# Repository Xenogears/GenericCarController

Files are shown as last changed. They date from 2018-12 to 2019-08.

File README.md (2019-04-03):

# Generic Car Controller
It is a device designed to improve the capabilities of vehicles in an automotive environment.
This custom controller connects to an existing CAN Bus on the vehicle and acts like another component of the system.

### Motivation
It is very common that certain car features are locked by the manufacturers in its mid/low-series products or that its embedded systems are restricted to work with a limited array of devices.
There even are internal parameters hidden to customer's usage. These parameters may be helpful in order to predict potential malfunctions and enhances the security and the reliability of the vehicle.

### Compatibility with specific car models
Even though the project is developed and tested using an Opel Astra H (2004) it can be adapted and used with any vehicle which uses a CAN BUS network to communicate across its devices.

Other car models must be defined inside the "cars/" folder following the defined structure in the "DefaultCar" model.

### Hardware setup
The project is not closed to a specific hardware device but it is developed focusing on the ATMega brand microprocessors with multiple peripheral connected via the SPI interface.

The latest prototype version (4.3) was built using the following components:
* 1x - Arduino Nano v3 (ATMega 328p)
* 1x - MCP 2515 CAN Controller board
* 1x - MCP4131 Potentiometer
* 1x - PC817 Optocoupler
* 1x - HC-05 Bluetooth interface (Optional, used for wireless debugging and configuration)
* 1x - SIM800L GSM Module
* 1x - GY-NEO6MV2 GPS Module

You can build your own with the schematic and the gerber file located inside the "Board/" folder.
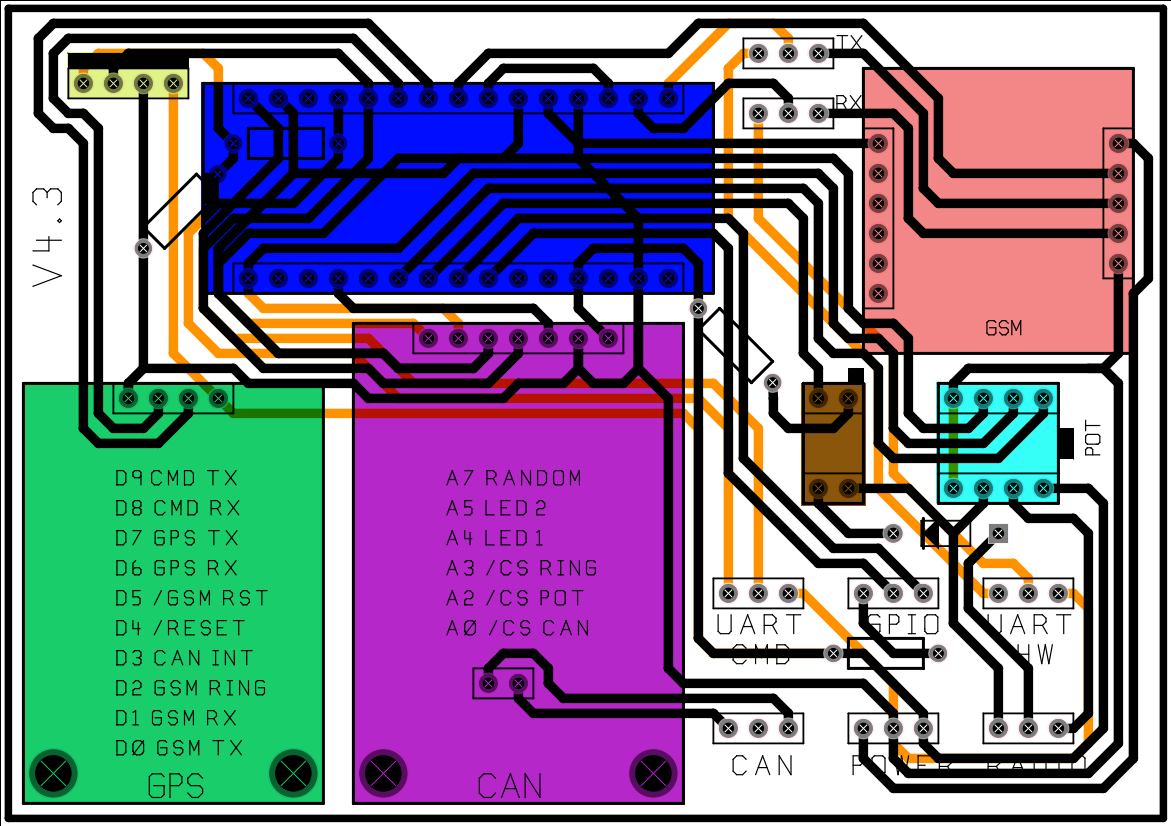
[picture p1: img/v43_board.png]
Prototype V4.3


### Previous prototypes
For learning purposes you can see inside the "img/" folder the progression of already built prototypes and how they were improved. 
<br/>
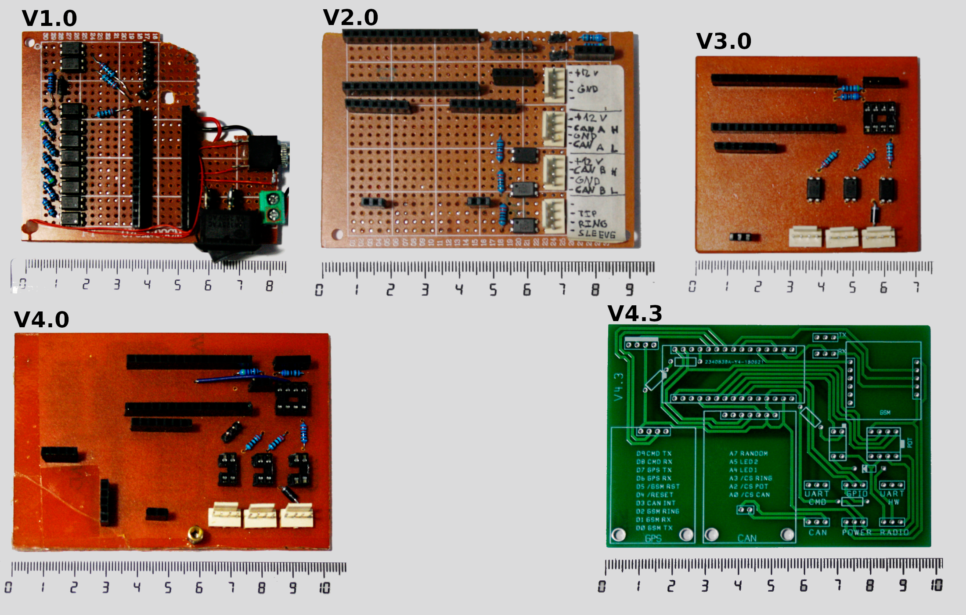
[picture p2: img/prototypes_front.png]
Prototypes (Front view)

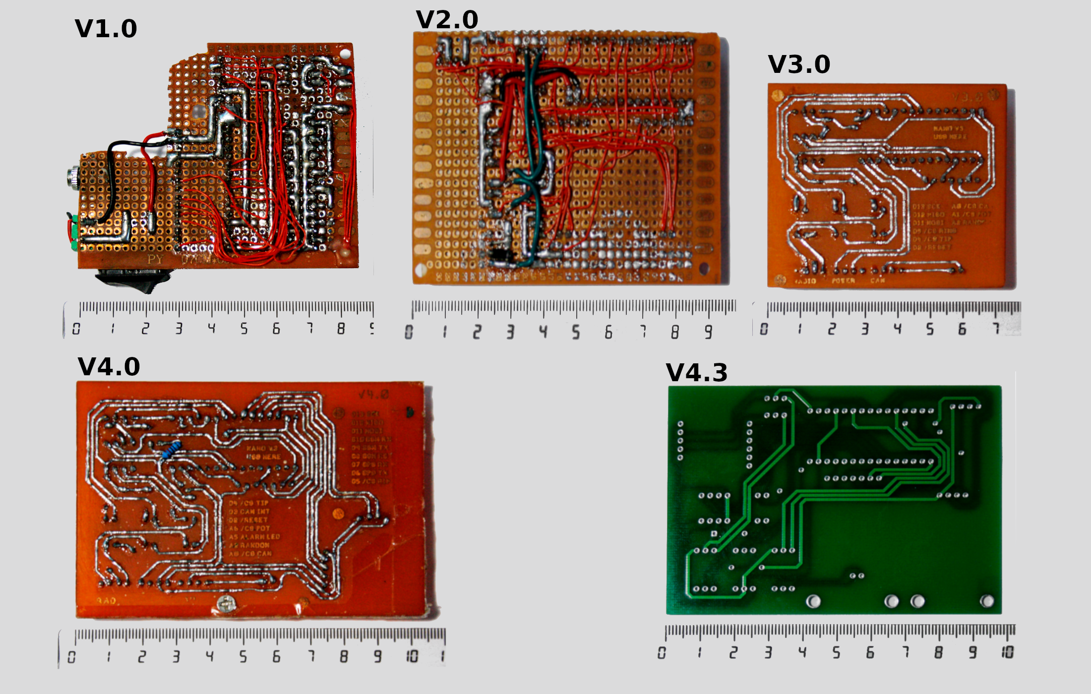
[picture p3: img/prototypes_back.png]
Prototype (Back view)


### License
Author:	  Álvaro Graciá Gil<br/>
License:	This work is licensed under a Creative Commons Attribution-NonCommercial-ShareAlike 4.0 International License<br/>
	 		    (http://creativecommons.org/licenses/by-nc-sa/4.0/)<br/>

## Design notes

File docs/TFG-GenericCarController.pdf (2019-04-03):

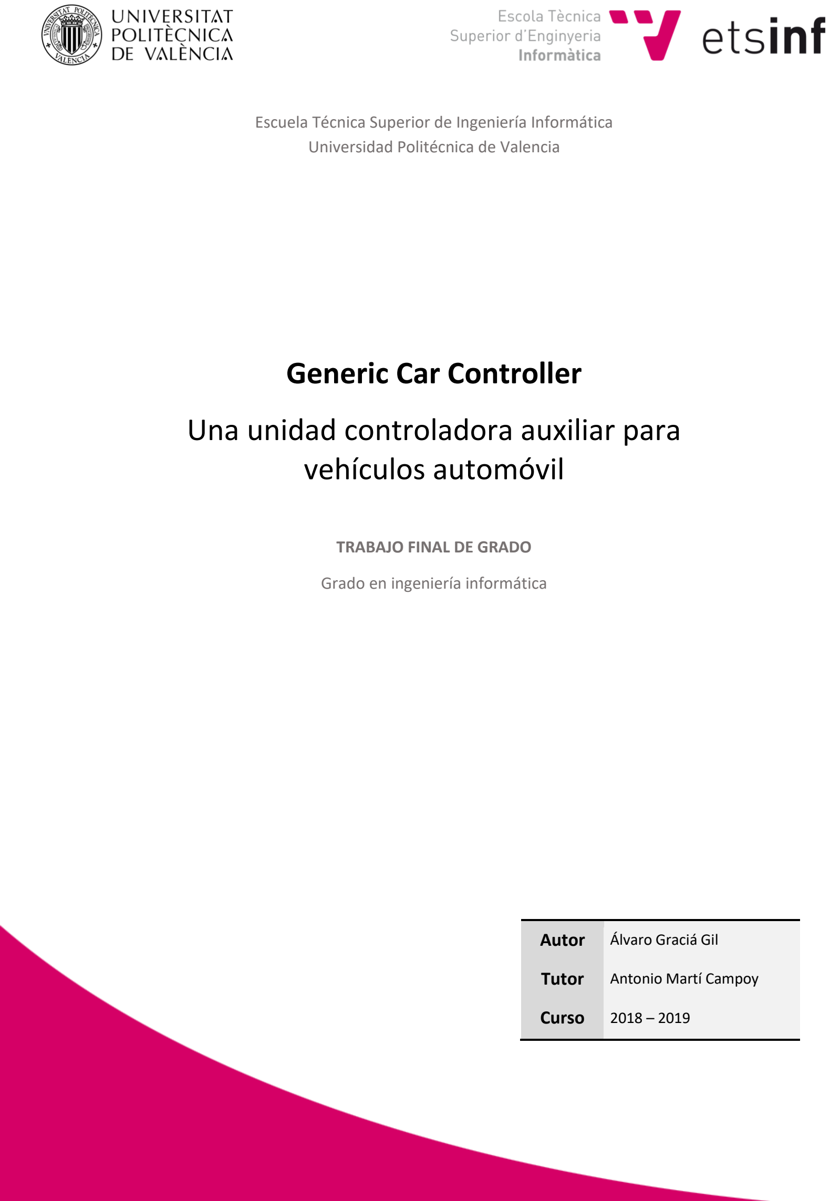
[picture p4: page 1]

Escuela Técnica Superior de Ingeniería Informática Universidad Politécnica de Valencia

# Generic Car Controller

# Una unidad controladora auxiliar para vehículos automóvil

TRABAJO FINAL DE GRADO

Grado en ingeniería informática

Autor | Álvaro Graciá Gil
Tutor | Antonio Martí Campoy
Curso | 2018 – 2019

## Esta obra está bajo una licencia de Creative Commons Reconocimiento – No Comercial – Compartir Igual 4.0 Internacional. (http://creativecommons.org/licenses/by-nc-sa/4.0/)

GitHub del proyecto https://github.com/Xenogears/GenericCarController

Dedicado a mi familia. Gracias a todos por darme la posibilidad de completar mis estudios y ayudarme durante todos estos años de formación y crecimiento personal.

## RESUMEN

Este documento trata sobre el diseño y la implementación de una controladora para vehículos automóvil.

Está formada por un componente hardware basado en un sistema microcontrolador, el cual se integra a través del bus de datos CAN en los sistemas existentes en la mayoría de los vehículos actuales. Y, por otra parte, del software específico incluido en el propio microcontrolador, el cual gestiona las comunicaciones con el automóvil y le dota de características adicionales y personalizadas.

Algunos ejemplos de las funcionalidades implementadas son:
- El control de una radio no original a través de los botones incorporados en el volante
- Un sistema de diagnóstico que permite en tiempo real la obtención de múltiples parámetros del automóvil que normalmente son inaccesibles.
- Un sistema de geolocalización 24/7.
- El uso de la pantalla original del vehículo para mostrar notificaciones y textos personalizados.
- Control y configuración del sistema a través de una aplicación móvil para Android.

Palabras clave: Controladora para vehículos automóvil, CAN BUS, Geolocalización, Arduino, Android, GPS, GSM, Traccar, Potenciómetro digital, Sistemas Empotrados

## RESUM

Aquest document tracta sobre el disseny i la implementació d’una controladora per a vehicles automòbil.

Està formada per un component hardware basat en un sistema microcontrolador, el qual s’integra a través el bus de dades CAN en els sistemes existents en la majoria dels vehicles actuals. I, d’altra banda, del software específic inclòs en el propi microcontrolador, el qual gestiona les comunicacions amb l’automòbil i el dota de característiques addicionals i personalitzades.

Alguns exemples de les funcionalitats implementades són:
- El control d’una ràdio no original a través dels botons incorporats al volant.
- Un sistema de diagnòstic que permet en temps real l’obtenció de múltiples paràmetres de l’automòbil que normalment són inaccessibles.
- Un sistema de geolocalització 24/7.
- L’us de la pantalla original del vehicle per mostrar notificacions i textos personalitzats.
- Control i configuració del sistema mitjançant una aplicació mòbil per a Android.
Paraules clau: | Controladora per a vehicles automòbil, CAN BUS, | Geolocalització, Arduino,
Android, GPS, GSM, Traccar, Potenciòmetre digital, Sistemes Encastats.

## ABSTRACT

This document deals with the design and the implementation of a custom controller for an automotive vehicle.

It consists of a hardware component based on a microcontroller system, which uses a CAN data bus to integrate with the existing systems available in the majority of current vehicles. And, on the other hand, the specific software included in the microcontroller itself, which manages the communications with the vehicle and gives it additional and personalized functions.

Some examples of the implemented functions are:

- Control of a non-original stereo system through the built-in buttons on the steering wheel.
- A diagnostic system that allows in real time to fetch multiple internal parameters those normally are inaccessible.
- A 24/7 geolocation platform.
- A notification manager which can show personalized texts on the original screen of the vehicle.
- Control and configuration of the system using a mobile application for Android.

Keywords: Vehicle controller, Automotive controller, CAN BUS, Geolocation, Arduino, Android, GPS, GSM, Traccar, Digital potentiometer. Embedded Systems.

## ÍNDICE

### ÍNDICE DE TABLAS

TABLA 27 – OPEL ASTRA H – FORMATO DEL MENSAJE DE LA PULSACIÓN O LIBERACIÓN DE LOS BOTONES DEL VOLANTE.......56

### ÍNDICE DE ILUSTRACIONES

### GLOSARIO DE TÉRMINOS

Android: Es un sistema operativo basado en el núcleo de Linux. Fue diseñado principalmente para dispositivos móviles con pantalla táctil, como teléfonos inteligentes o tabletas, aunque posteriormente se añadió soporte para relojes inteligentes, televisores y automóviles.

APN: De sus siglas “Access Point Name” o “Nombre del Punto de Acceso”. Es un nombre de host que se emplea normalmente en telefonía y que sirve para obtener la dirección IP del proveedor del servicio de acceso a una red de datos de comunicación inalámbrica externa.

Arduino: Es una plataforma para crear prototipos electrónicos, la cual está basada en hardware y software libre. Cuenta con un gran abanico de modelos distintos según las necesidades que se requieran. Se creó en el año 2005 por Massimo Banzi para cubrir la necesidad académica del resto de estudiantes de su mismo centro, aunque posteriormente creció y acabó convirtiéndose en una de las plataformas más extendidas y reconocidas en su ámbito.

Bluetooth: Es un estándar abierto para transmitir información a través de redes Inalámbricas de área personal (WPAN). Permite la transmisión de voz y datos entre dispositivos utilizando un enlace por radiofrecuencia en la banda ISM de los 2.4 GHz.

BNF: Notación de Backus-Naur. Es una técnica de notaciones usada para describir la sintaxis de lenguajes formales como lenguajes de programación, documentos, conjuntos de instrucciones o protocolos de comunicaciones.

CAD: De sus siglas “Computer-Aided Design” o “Diseño Asistido por Ordenador”. Es el proceso de crear la representación de un objeto tridimensional a través de un software especializado.

CAN: De sus siglas “Controller Area Network”. Es un protocolo de comunicaciones desarrollado por la firma alemana Bosch para el intercambio de información entre unidades de control empleando una topología en bus.

Controlador: Es un componente electrónico o un software que se integra entre varios sistemas y realiza funciones de gestión y control en el entorno que se integra.

EEPROM: De sus siglas “Electrically Erasable Programmable Read-Only Memory” o “Memoria de Sólo Lectura Borrable Electrónicamente”. Es un tipo de memoria ROM no volátil que puede ser programada y borrada utilizando una corriente eléctrica.

ESP: Es el nombre que recibe el sistema de control de estabilidad en automóviles. Se trata de un dispositivo de seguridad activa que actúa frenando individualmente cada rueda en situaciones de riesgo para evitar que patine o derrape.

Geocerca: Es un perímetro virtual en un mapa, el cual permite establecer los límites de una ubicación física para realizar tareas de monitorización o seguimiento.

Gerber: Es un formato de archivo estandarizado en la industria, el cual contiene toda la información necesaria para la fabricación de un circuito impreso.

GPIO: De sus siglas “General Purpose Input/Output” o “Entrada/Salida de Propósito General”. Es un terminal de un integrado que puede ser utilizado como una entrada para obtener el valor binario correspondiente a la señal que se encuentra en ese terminal, o también puede ser una salida y establecer el nivel lógico al que está el terminal.

GPS: De sus siglas “Global Positioning System” o “Sistema de Posicionamiento Global”. Es un sistema de navegación que, mediante el uso de satélites, permite determinar la posición de cualquier objeto alrededor del planeta con una precisión teórica de centímetros, aunque en la práctica son unos pocos metros.

GSM: De sus siglas “Global System for Mobile Communication” o “Sistema global para las comunicaciones móviles”. Es un estándar de telefonía móvil digital que define un sistema para la transmisión de voz, mensajes de texto y datos entre dispositivos móviles empleando antenas de telefonía distribuidas por el proveedor.

I2C: De sus siglas “Inter-Integrated Circuit” o “Circuito Inter-Integrado”. Es un tipo de bus serie de datos. Se utiliza principalmente para la comunicación entre diferentes integrados de un mismo circuito.

IDE: De sus siglas “Integrated Development Environment” o “Entorno de Desarrollo Integrado”. Es un conjunto de aplicaciones que proporcionan al programador herramientas y servicios con la intención de facilitarle el desarrollo de software.

Interrupción: Es una señal recibida por el procesador para indicarle que debe atender una situación prioritaria. Esto detendrá el flujo de ejecución actual y pasará a ejecutar un código específico asociado a dicha señal. Tras esta ejecución, el flujo de ejecución se restaurará y continuará en el punto donde había sido interrumpido.

IoT: De sus siglas “Internet Of Things” o “Internet De las Cosas”. Es un concepto que se refiere a la interconexión digital total de objetos cotidianos y dispositivos a través de internet.

LED: De sus siglas “Light-Emitting Diode” o “Diodo Emisor de Luz”. Se trata de una fuente de luz constituida por un diodo de unión p-n que emite luz cuando está activo.

MOSFET: Es un dispositivo semiconductor utilizado para amplificar o conmutar señales electrónicas. Es el transistor más utilizado actualmente en la industria electrónica.

PCB: De sus siglas “Printed Circuit Board” o “Placa de Circuito Impreso”. Es una superficie que cuenta con caminos, pistas y buses de material conductor sobre una base no conductora. El circuito impreso se utiliza para conectar eléctricamente, y sostener mecánicamente distintos componentes electrónicos.

Polling: En castellano “Sondeo”. Se refiere a una consulta periódica, generalmente hacia un dispositivo de hardware.

Potenciómetro: Es un resistor variable, el cual varía su valor resistivo entre sus terminales en función de la posición indicada por el usuario.

Raspberry Pi: Es un ordenador de placa reducida de diseño libre. Cuenta con gran cantidad de software adaptado y ofrece altas prestaciones a bajo coste.

SIM: Es una tarjeta inteligente desmontable usada en teléfonos móviles y módems GSM. Las tarjetas SIM almacenan de forma segura en su interior la clave necesaria para identificarse ante la red del proveedor.

SPI: De sus siglas “Serial Peripheral Interface” o “Interfaz Serie para Periféricos”. Es un estándar de comunicaciones, usado principalmente para la transferencia de información entre circuitos integrados.

UART: De las siglas “Universal Asynchronus Receiver-Transmitter” o “Transmisor-Receptor Asíncrono Universal”. Es un dispositivo que controla los puertos y dispositivos serie. Normalmente se encuentra integrado en el microcontrolador o en una tarjeta adicional del dispositivo.

UTC: Es el principal estándar de medición de tiempo por el cual se regulan y sincronizan los relojes a nivel mundial.

Watchdog: Conocido como “Perro guardián”. Es un mecanismo de seguridad que provoca un reinicio del sistema en caso de que éste se haya bloqueado.

Wired/Remote: Protocolo utilizado para controlar equipos de sonido mediante un mando a distancia cableado. Lo incorporan los sistemas de las marcas Sony, Kenwood y Pioneer.

## 1 – INTRODUCCIÓN Y OBJETIVOS

Conforme los automóviles se han ido modernizando, los sistemas internos han dejado de ser únicamente mecánicos y se han convertido en sistemas inteligentes, controlados mediante microcontroladores repartidos por todo el vehículo. Actualmente los automóviles cuentan con decenas de microcontroladores y dispositivos interconectados entre sí ¹

Para ello principalmente utilizan una tecnología de comunicación en bus llamada CAN BUS. Esta tecnología fue estandarizada (ISO 11898 [14]) a finales de la década de 1990 y define un protocolo de comunicaciones que es ampliamente utilizado en automoción y en la industria. Por ejemplo, algunos ascensores o robots se comunican utilizando CAN BUS.

Este documento presenta el desarrollo de una controladora genérica que se conecta al bus de datos de un automóvil y le permite al usuario acceder a nuevas funciones. Dichas funciones no están limitadas a un único modelo de vehículo determinado, ya que el proyecto se estructura de forma genérica para que resulte sencillo implementar nuevas funcionalidades y a su vez sean abstraídas de forma que múltiples modelos y marcas se beneficien de las mismas prestaciones con poco esfuerzo en la implementación.

Resulta muy común que los vehículos dispongan de funcionalidades extra que se encuentran bloqueadas de fábrica en algunos modelos o versiones de gama media/baja. También es frecuente que los sistemas internos se desarrollen para que únicamente funcionen sin limitaciones con dispositivos originales o autorizados. Un ejemplo representativo son los sistemas de sonido, donde es posible que al cambiar la radio original por otra no oficial dejen de funcionar ciertas características, como los controles integrados en el volante o incluso el sistema de “manos libres”.

También ocurre que ciertas opciones se encuentran deshabilitadas para el mercado general porque no resultan útiles para la mayoría de los clientes, aunque sí lo son para otros. Un ejemplo práctico es la posibilidad de obtener en tiempo real algunos datos del vehículo para analizarlos y detectar valores anómalos o posibles averías.

En esos casos y más tiene cabida una controladora adicional personalizada, la cual permite aumentar las prestaciones que ofrece el sistema de fábrica e interceptar información útil directamente desde los sensores y otras unidades del vehículo.

### 1.1 – OBJETIVOS

El objetivo principal de este trabajo es crear un dispositivo el cual se conecte e integre en un vehículo automóvil con la finalidad de incrementar sus funcionalidades.

Tanto el diseño del apartado hardware como el apartado software deben ser altamente genéricos y parametrizables de forma que se adapten al amplio abanico de posibles modelos de automóvil existentes en el mercado.

1 | Artículo | sobre | la | evolución | de | las | unidades | electrónicas | en | automóviles
https://www.embitel.com/blog/embedded-blog/automotive-control-units-development-innovations-mechanical-to-electronics

Debido al entorno donde debe funcionar, el ensamblado completo debe ser de un tamaño reducido para facilitar su colocación en el interior del vehículo, además de tener un bajo consumo energético.

Por otra parte, las funcionalidades adicionales deben ser completamente configurables y adaptables, de forma que con simples ajustes funcionen con cualquier modelo de automóvil.

Algunas de estas funcionalidades deben ser:
- Acceder a la información interna del automóvil a través de la pantalla integrada en él.
- Integrar los controles del volante y el salpicadero con equipos de audio multimarca.
- Geolocalizar el vehículo en tiempo real.
- Control remoto del sistema de forma inalámbrica.

## 2 – REQUISITOS

A continuación, se presentan los requisitos que debe cumplir la controladora. Estos requisitos se desglosan en requisitos hardware, software y funcionales.

### 2.1 – REQUISITOS HARDWARE

- Debe ser compatible a nivel eléctrico con el vehículo.
- Debe comunicarse con el automóvil a través de un bus de datos CAN. Por razones de seguridad, este bus de datos debe estar diferenciado del empleado en el bloque motor del vehículo.
- El computador utilizado debe disponer al menos de las siguientes características:
- Al menos 2KB de memoria RAM y 32KB para el código.
- Una interfaz UART.
- Conectividad SPI e I2C.
- Conectores GPIO adicionales que puedan ser empleados para manejar periféricos sencillos como por ejemplo LEDs o módulos de radio frecuencia.
- Debe incluir una controladora CAN BUS conectada a la CPU.
- Toda la controladora y sus componentes deben estar ensamblados en una única placa de pequeñas dimensiones, la cual se colocará dentro de un mecanizado para evitar problemas como falsos contactos y derivaciones eléctricas.

### 2.2 – REQUISITOS SOFTWARE

- El desarrollo debe realizarse manteniendo un equilibrio entre eficiencia, consumo reducido de memoria RAM y un tamaño del ejecutable aceptable.
- El código debe seguir una estructura que facilite su fiabilidad y seguridad.
- El sistema debe arrancar y ser completamente funcional en pocos segundos.
- Debe tener una estructura que permita añadir o quitar funcionalidades de forma sencilla. Estas funcionalidades se añadirán en forma de módulos software, los cuales serán partes de código enfocadas a dotar a la controladora y/o al vehículo de nuevas características.
- La forma de implementar las nuevas funcionalidades por parte de los módulos software debe ser lo más genérica posible, de forma que sean válidas para cualquier modelo de vehículo cambiando parámetros en la configuración o añadiendo pequeños códigos únicos de cada modelo de automóvil.
- Tanto el software principal como los módulos software expondrán al exterior una serie de acciones que serán registradas en el arranque. Estas acciones serán las empleadas por el usuario y por el resto de módulos para utilizar las funciones que aporten.
- El software debe contar con un fichero de configuración donde se indiquen los parámetros y módulos a emplear en tiempo de compilación.
- Los parámetros deben estar en forma de sentencias del pre-procesador o expresiones constantes.
- Se debe poder indicar el vehículo y los módulos que se van a utilizar para que en tiempo de compilación se enlace el código y se carguen las configuraciones específicas para ese automóvil.

- Se debe poder indicar la velocidad de funcionamiento del CAN BUS y la frecuencia del oscilador conectado al módulo CAN.
- Deben poder existir opciones modificables en tiempo de ejecución. Esta serie de opciones deben contar con algún sistema para almacenarlos de forma persistente y que no se pierdan tras el apagado.
- Debe incluir un sistema de registro de información, de forma que sea posible visualizar el funcionamiento de la controladora en tiempo real a través de la interfaz serie.
- Debe haber un sistema de comunicaciones bidireccional que emplee la interfaz serie para recibir comandos. Este sistema de comunicaciones debe poder:
- Ver, modificar o eliminar las opciones en tiempo real.
- Gestionar el sistema de registro para detallar qué debe ser mostrado.
- Invocar distintas acciones dependiendo del comando recibido.
- Los comandos deben estar en formato texto para facilitar su escritura al usuario.
- Incluir las siguientes acciones de forma predeterminada:
- Obtener la memoria RAM libre del sistema.
- Configurar el watchdog y las interrupciones del sistema.
- Reiniciar el sistema.
- La misma acción debe poder ser registrada varias veces desde distintos módulos software para poder ser manejada por todos.

### 2.3 – REQUISITOS FUNCIONALES

Estos requisitos centran en las funcionalidades adicionales para controladora en sí y para el automóvil. Es importante destacar que estos requisitos dependen directamente de las funciones adicionales que se vayan a emplear.

- Interceptar los mensajes CAN asociados a las pulsaciones de los botones físicos que se sitúan en el salpicadero, en el volante o cualquier otro lugar accesible para el usuario y asociarlas de forma sencilla a la ejecución de acciones personalizadas.
- Controlar equipos de sonido que cumplen el protocolo Wired/Remote, los cuales están diseñados especialmente para automóviles.
- Para ello se debe conectar un potenciómetro digital que soporte un rango de resistencias entre 0Ω y 62.5Ω.
- También se debe conectar algún sistema para conmutar señales de forma digital, ya sea por GPIO, SPI o I2C.
- Geolocalizar el automóvil y obtener información sobre él en tiempo real a través de internet garantizando la privacidad y la seguridad de las conexiones.
- A nivel de hardware se debe conectar por UART, SPI o I2C:
- Un modem GSM.
- Un receptor GPS que soporte el estándar NMEA 0183 [8] [15].
- Requiere de una plataforma de seguimiento accesible a través de internet.
- A través de una aplicación móvil, acceder a las acciones, a las opciones y a los registros de forma inalámbrica.
- Requiere de un módulo Bluetooth conectado al UART principal.

- Requiere de un terminal móvil o tablet que disponga de conectividad Bluetooth.
- A través de mensajes CAN, utilizar la pantalla integrada del automóvil para mostrar textos con caracteres alfanuméricos, ya que va a ser el medio principal para visualizar datos directamente desde la controladora.
- En caso de que el texto a mostrar tenga una longitud demasiado larga y no quepa en las dimensiones de la pantalla, se debe realizar un efecto de marquesina deslizante para que se visualice el texto progresivamente.
- El sistema debe ser capaz de acceder a la configuración básica del vehículo para leer o modificarla. Por motivos de seguridad, dichos parámetros no pueden estar relacionados directamente con la conducción. Ejemplo de configuración sí accesible: la hora y fecha del automóvil.
- El software debe incluir un modo de simulación de vehículo. A rasgos generales, debe ser capaz de invertir las funciones de la controladora para que esta actúe como un vehículo en sí y se puedan realizar pruebas fuera del automóvil simulando un entorno completo.

## 3 – DISEÑO E IMPLEMENTACIÓN HARDWARE

### 3.1 – ESQUEMA BÁSICO

El apartado de hardware sigue el esquema de la ilustración 1:

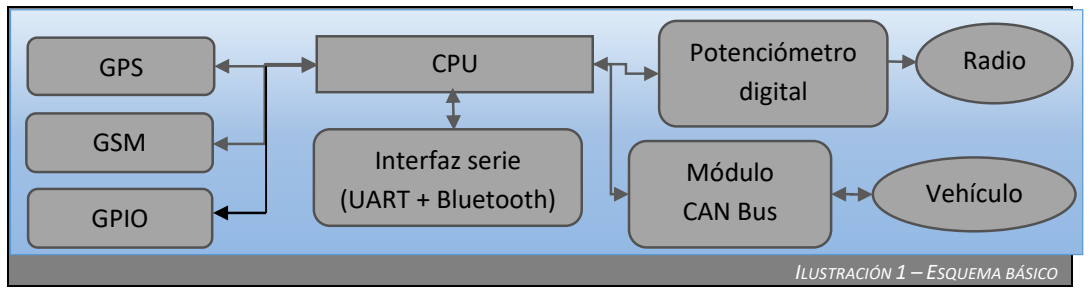
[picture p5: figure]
ILUSTRACIÓN 1 – ESQUEMA BÁSICO; GPS; CPU; GSM; Potenciómetro digital; Radio; Módulo CAN Bus; Vehículo; Interfaz serie (UART + Bluetooth); GPIO

- La CPU gestiona todos los componentes y decide qué acciones llevar a cabo según los datos de entrada que reciba. Principalmente la información se recibe desde el CAN BUS, aunque también puede llegar de la mano del módulo GSM o de la interfaz serie.
- Los módulos GPS y GSM en conjunto permiten geolocalizar el automóvil y comunicar su posición a un servidor, además de notificar distintos cambios en el vehículo como el estado del contacto, voltaje de la batería, excesos de velocidad, etc…
- El GPIO sirve para extender la funcionalidad de la controladora mediante dispositivos externos sencillos como LEDs o módulos de radiofrecuencia.
- El potenciómetro se emplea para enviar órdenes a equipos de sonido.
- El módulo CAN (o módulos CAN, no está limitado a un único bus) es uno de los componentes más importantes que forman la controladora del vehículo. Gestiona todas las comunicaciones con el automóvil y por ello se vuelve un componente crítico e imprescindible.
- La interfaz serie permite interactuar con el software de la controladora a través de comandos y gestionar la controladora en tiempo real.

### 3.2 – ELECCIÓN DE PLATAFORMA

Durante la fase de diseño se valoraron distintas plataformas que tomar como base para construir el sistema. Principalmente se plantearon Raspberry Pi [10] y distintos modelos de Arduino [11].

Se llevaron a cabo distintas pruebas con la Raspberry Pi. La velocidad de respuesta era muy rápida, pero tenía una serie de problemas:

- La Raspberry Pi necesita un sistema operativo para funcionar, lo que implica un arranque mucho más lento en comparación a un microcontrolador sin sistema operativo. Se probó una distribución de Linux basada en Debian además de Windows IoT [3]. Ambos sistemas eran muy lentos al arrancar, ya que comenzaban a funcionar completamente pasadas unas decenas de segundos o incluso minutos.
- Aunque el consumo eléctrico de una Raspberry Pi es bajo en términos absolutos, es demasiado elevado si pensamos en dejar el sistema siempre encendido alimentándose de la batería del automóvil. La Raspberry Pi consume alrededor de 200mA/h mientras que, por ejemplo, un Arduino Nano con todos los componentes adicionales empleados (GPS, GSM, CAN, etc…) en funcionamiento ronda los 80mA/h.
- Por la forma que tiene resulta complicado situar componentes uno al lado del otro, obligando a colocarlos encima a modo de shield. Esto limita la libertad de diseño del hardware y dificulta la creación del circuito con dimensiones reducidas.
- Durante su funcionamiento, la Raspberry Pi puede aumentar mucho su temperatura, lo cual obligaría a utilizar algún sistema de refrigeración activo como un ventilador. Esto dificultaría la integración en el vehículo.
- El coste económico es mayor en comparación a otras posibles soluciones.

Tras esto se decidió tomar Arduino como la plataforma a emplear, ya que su diversidad de modelos permitió elegir el componente idóneo cumpliendo con los objetivos.

### 3.3 - ALIMENTACIÓN

La mayoría de los automóviles trabajan a tensiones de 12V o raramente a 24V [16], aunque carecen de estabilidad en la señal. Por ejemplo, durante el arranque, la tensión de un automóvil que funciona a 12V puede bajar hasta 9V y un par de segundos después, cuando el alternador comienza a generar electricidad, se producen picos de alrededor de 14.5V.

Para conseguir regular la tensión de entrada a los 5V de funcionamiento que requiere el Arduino, este cuenta con un regulador de voltaje lineal integrado que admite tensiones entre 6V y 20V. Para el caso de algunos vehículos este rango puede no ser lo suficientemente amplio. Y aunque así sea, es muy susceptible a quemarse tras múltiples encendidos debido a la inestabilidad de la tensión.

Por ello se decide utilizar una fuente conmutada a la entrada que estabilice la tensión a 5V. Estas fuentes rondan el 98% de eficiencia y no aumentan tanto su temperatura en funcionamiento en comparación a los reguladores lineales.

Para alimentar el Arduino Nano V3 con una fuente externa, en lugar de usar el pin VIN se utiliza el pin +5V, puenteando así el regulador interno y evitando que entre en funcionamiento. Hay que tener en cuenta que en algunos modelos de Arduino esto deshabilita también el pin de +3.3V.

En el caso de utilizar el modem GSM SIM800L debemos tener en cuenta que este se alimenta a 3.7V (aunque algunos fabricantes indican que funciona correctamente a 5V) y que en las fases de conexión a la red requiere de unos picos de corriente muy elevados (rondando el amperio), por lo que es recomendable utilizar otra fuente sólo para este módulo.

Al ser un dispositivo que potencialmente va a estar encendido siempre y alimentándose de una batería es de vital importancia tener en cuenta el consumo total del sistema para no agotar completamente la batería del automóvil y mermar el arranque del vehículo.

Se recomienda utilizar una batería adicional para esta controladora o tomar la alimentación directamente del contacto para que sólo funcione con el automóvil encendido y generando corriente mediante el alternador.

### 3.4 – COMPONENTES

A continuación, se van a citar los componentes electrónicos con los que se ha realizado la implementación del proyecto. Estos componentes permiten alcanzar los objetivos y requisitos de este proyecto además de mantener un buen equilibrio entre rendimiento y coste económico.

Es importante destacar que el proyecto permite el uso de hardware diferente al mostrado tras este párrafo. Dependiendo del vehículo en que se vaya a emplear y de las características del mismo es posible que se tengan que cambiar ciertos componentes o que simplemente no sean todos necesarios.

## CPU –ARDUINO NANOV3 (ATMEGA 328P)

Por su sencillez, facilidad de compra, precio reducido y documentación disponible, emplear Arduino es una opción muy atractiva. En el caso del Nano V3 su reducido tamaño es una ventaja añadida a la hora de integrarlo en un circuito que en circunstancias normales se colocará en pequeños huecos (guantera, bajo alguna tapa, detrás de la radio, etc…)

En la ilustración 2 se puede ver el Arduino Nano V3.

Incorpora el procesador ATMega 328P, el cual dispone de 32KB de memoria Flash para el código a ejecutar y 2KB de memoria RAM. Estas características son suficientes para almacenar el ejecutable y los datos que requiere la controladora.

Este modelo de Arduino incorpora una interfaz UART hardware y 20 pines GPIO, los cuales son más que suficientes para este proyecto. Existen herramientas que permiten utilizar cualquier par de pines GPIO como una interfaz UART emulada por software. Aunque su rendimiento es menor, está comprobado que es suficiente y funciona correctamente con los componentes descritos a continuación.

## CAN BUS–MCP2515

Microchip dispone de un integrado llamado MCP2515, el cual gestiona las comunicaciones CAN siguiendo el estándar ISO 11898, el cual define un protocolo de comunicaciones en bus y es el que principalmente emplean los automóviles.

En la ilustración 3 se puede ver una placa comercial que ensambla el integrado MCP2515 y el transceptor TJA1050.

Las comunicaciones con el integrado se realizan mediante el protocolo SPI. Este integrado dispone de unos buffers que almacenan un máximo de dos mensajes en recepción y hasta tres para el envío, lo que resulta más que suficiente para las funcionalidades implementadas y las velocidades de bus típicas en los automóviles (generalmente un máximo de 500Kbit/s)

Para reducir la cantidad de mensajes recibidos a procesar, el integrado dispone de seis filtros que permiten establecer los identificadores válidos y descartar los mensajes indeseados. De

ARDUINO NANO V3

ILUSTRACIÓN 3 –
PLACA COMERCIAL MCP2515 esta forma se previenen problemas de desbordamiento en los buffers de recepción y transferencias innecesarias entre el integrado y la CPU.

Es muy importante elegir bien y tener presente el oscilador que acompaña al MCP2515, pues este decidirá los parámetros temporales que se deben utilizar a la hora de configurar la velocidad del bus de datos. Para ello resulta conveniente calcularlos previamente 2
y ver si
genera alguna desviación temporal que pueda comprometer las comunicaciones.

## POTENCIÓMETRO –MCP4131

No existe un estándar oficial que permita manejar los equipos de sonido, aunque afortunadamente existe un protocolo acordado entre varias marcas líderes en el sector.

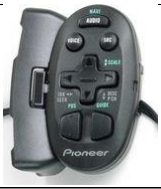
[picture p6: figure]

Esta tecnología se conoce como “Wired Remote (W/R)” y está
presente en equipos de sonido de las marcas Sony, Pioneer y
Kenwood. Estas marcas copan el mercado de las autoradios de
gama media y alta.

Esta tecnología emplea un conector Jack tripolar hembra de 3.5mm situado en la parte trasera de la radio para conectar un mando a distancia fabricado y suministrado por la marca. Se puede ver el mando en la ilustración 4 y el conector Jack macho
en la ilustración 5.

Este mando simplemente cuenta en su interior con un conjunto de
resistencias conectadas entre los botones y los terminales del conector en el extremo del cable. Cada acción enviada a la radio se corresponde con el valor específico de una resistencia entre los terminales “Tip” y “Sleeve” del conector Jack.

De esta forma, el equipo de sonido mide la resistencia entre los
terminales del conector Jack y procesa la señal correspondiente.

Las señales enviadas al equipo de sonido deben mantenerse activas durante un tiempo mínimo de 50 milisegundos para ser procesadas correctamente y hasta un máximo de 110 milisegundos antes de que se asuma como una acción nueva y se procese repetidas veces.

El Jack cuenta con un terminal más llamado “Ring”, el cual si se conecta el terminal “Sleeve” se puede variar la acción enviada,
duplicando así la cantidad de señales posibles.

Por razones de seguridad, se recomienda incorporar un diodo
entre estos terminales para evitar corrientes de retorno hacia el equipo de sonido.

La forma más sencilla para variar la resistencia a voluntad a través de código software es mediante el uso de un potenciómetro digital.

2 CAN Bus Bit Timing Calculator - https://www.kvaser.com/support/calculators/bit-timing-calculator/

ILUSTRACIÓN 4 – MANDO WIRED REMOTE

ILUSTRACIÓN 5 – CONECTOR JACK

El MCP4131 es el integrado idóneo, pues su resistencia máxima es de 100KΩ con una precisión de 129 pasos (770Ω por paso), lo que es suficiente para los valores que se indican en los requisitos. Se puede ver el encapsulado en la ilustración 6.

La ilustración 7 muestra las conexiones de que
dispone este potenciómetro. Su interfaz de
comunicaciones es SPI al igual que la controladora CAN, lo cual facilita el desarrollo y reduce el uso de pines GPIO necesarios a sólo un pin adicional. (Pin 1 → CS / Chip Select)

## OPTOACOPLADOR–PC817X

Para enviar señales a los equipos de sonido, además del potenciómetro, para el control de la radio es necesario incorporar un mecanismo para interconectar el terminal “Ring” con el terminal “Sleeve” del conector Jack.

Para ello existe un abanico de opciones como transistores, MOSFETs o incluso relés [5].

El optoacoplador PC817X (se puede ver en la ilustración 8) es un componente adecuado ya que cumple con los requisitos y tiene un coste muy bajo. Este optoacoplador está formado por un encapsulado que incluye en su interior un diodo LED y un transistor que se activa mediante luz. Estos componentes están separados entre sí, pero se posicionan de forma que al aplicar tensión al LED este se ilumina y activa a su vez la circulación de corriente a través del transistor (ver ilustración 9).

Las principales ventajas de este sistema son:
- La conmutación se realiza sin partes mecánicas, lo que aumenta la vida útil del componente al evitar desgaste.
- No crean grandes campos magnéticos que puedan generar ruido eléctrico en la señal.
- Tienen un consumo eléctrico casi despreciable.
- Son de un tamaño muy reducido.
- Tienen un coste económico muy bajo.

Debido a la tensión de funcionamiento del sistema y la tensión requerida por el diodo LED incorporado en el PC817X, es necesario colocar una resistencia a la entrada del componente para cumplir sus requisitos eléctricos y evitar daños. En este caso, con una resistencia de 220Ω es suficiente [13].

## GPS –GY-NEO6MV2

El receptor GPS elegido es el GY-NEO6MV2. Este receptor cumple con los requisitos, ya que utiliza el estándar NMEA 0183 [8] [15]. Se puede ver el receptor GPS en la ilustración 10.

La tensión a la que funciona este componente es la misma que el Arduino, por lo que la conexión se realiza directamente y sin complicaciones.

Incluye una antena cerámica de reducidas dimensiones, la cual puede ser fácilmente adherida en su parte trasera.

ILUSTRACIÓN 8 –
PC817X

ILUSTRACIÓN 9 –
ESQUEMÁTICO DEL PC817X

ILUSTRACIÓN 10 –
GY-NEO6MV2

ILUSTRACIÓN 6 –
MCP4131

PINOUT - MCP4131

## MODEM GSM –SIM800L

El modem GSM SIM800L (se puede ver en la ilustración 11) es un componente que dota de la opción de conectarse a la red móvil y comunicarse por internet.

Gracias a esto es posible conectarse con la controladora de forma remota o enviar al servidor ciertos parámetros del vehículo en tiempo real.

Dispone de una interfaz UART para establecer las configuraciones y enviar las solicitudes por la red mediante comandos AT, los cuales son ampliamente utilizados y conocidos en este tipo de dispositivos.

En el reverso cuenta con un zócalo para conectar una tarjeta Micro SIM, la cual se empleará para identificarse en la red GSM del proveedor correspondiente.

## BLUETOOTH –HC-05 / HC-06

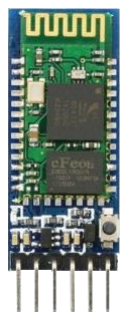
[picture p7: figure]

Para poder acceder a la controladora de forma inalámbrica se ha escogido el protocolo Bluetooth, ya que está ampliamente extendido en dispositivos móviles. El módulo HC-05/HC-06, el cual se puede ver en la ilustración 12, resulta adecuado para los requisitos del proyecto.

Debido a que el Arduino emplea una tensión de +5V para representar el nivel alto lógico en sus salidas, es necesario disminuir el voltaje hasta +3.3V al pin RX del módulo bluetooth. La forma más sencilla es mediante un divisor resistivo (es suficiente con resistencias de 2.2kΩ y 1kΩ), pero esto provoca un descenso en la velocidad máxima de transferencia y como máximo funciona correctamente a 115.200 baudios/s

## FUENTE DE ALIMENTACIÓN–DSN5000

En esta implementación se ha empleado la fuente de alimentación conmutada DSN5000 para suministrar a todo el hardware la electricidad en el voltaje correcto según los requisitos. Se puede ver el componente en la ilustración 13.

### 3.5 – ESQUEMÁTICO

A continuación, se detalla todo el esquemático de conexiones empleado, el cual corresponde a la versión 4.3 de la placa.

En la ilustración 14 se muestra el esquemático referente a la controladora CAN BUS. El conector J1 corresponde a la interfaz de comunicaciones con el MCP2515, mientras que los conectores J2 y J3 corresponden al conector de la placa base y al conector del propio bus del CAN.

ILUSTRACIÓN 11 –
SIM800L

ILUSTRACIÓN 12 –
HC-05 / HC-06

ILUSTRACIÓN 13 –
DSN5000

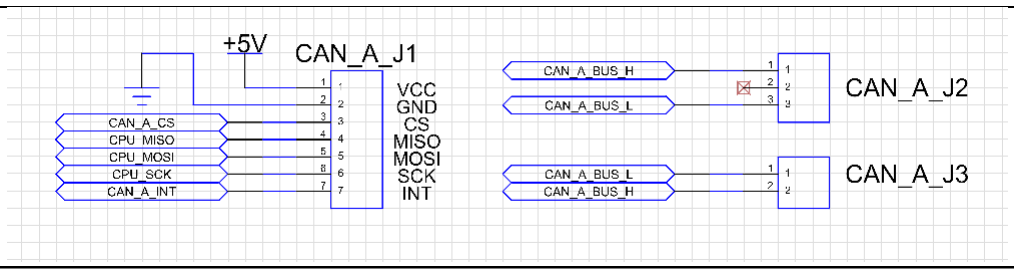
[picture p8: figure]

ILUSTRACIÓN 14 – ESQUEMÁTICO V4.3 (CAN BUS)

La ilustración 15 muestra todo el conexionado con el Arduino Nano V3.

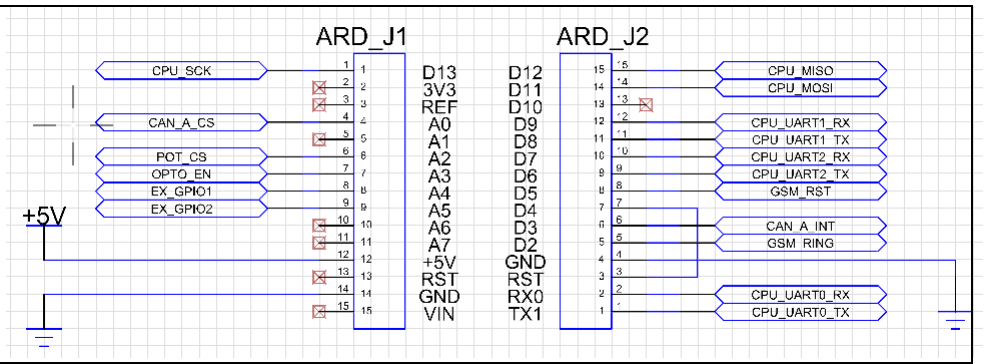
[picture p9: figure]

ILUSTRACIÓN 15 – ESQUEMÁTICO V4.3 (ARDUINO)

En la ilustración 16 se muestra el conector de alimentación, el conector externo GPIO y la interfaz serie externa. Esta interfaz serie cuenta con un conmutador para elegir si se conecta al puerto UART hardware del Arduino (el cual se utiliza para programarlo) o a un puerto UART alternativo.

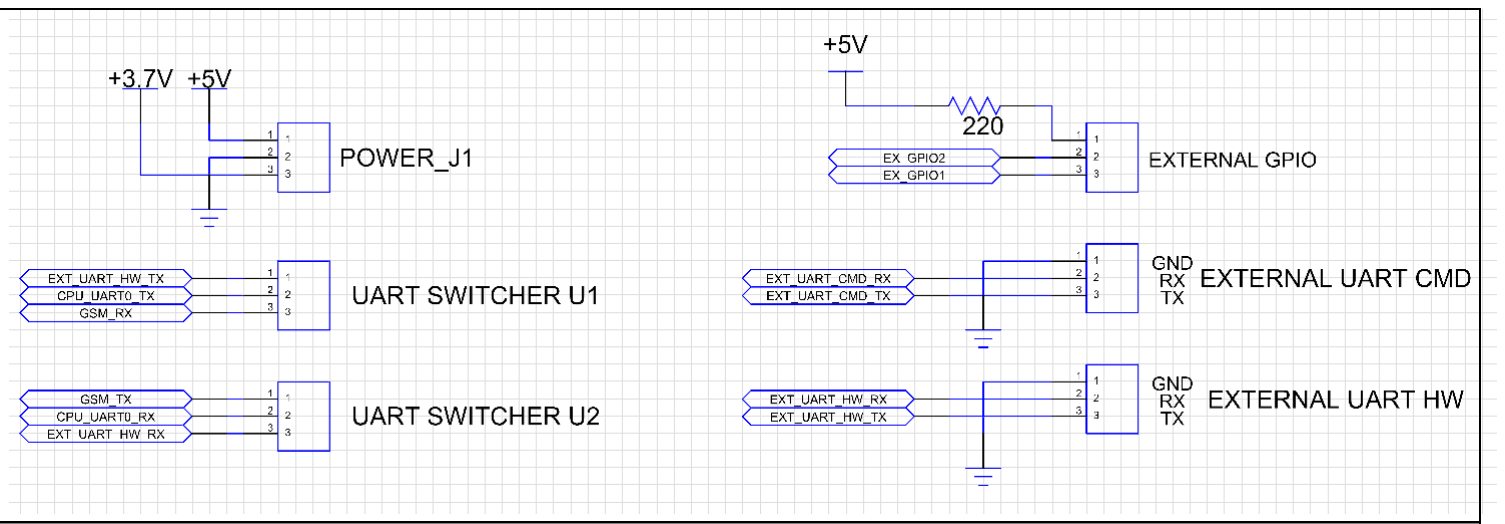
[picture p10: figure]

ILUSTRACIÓN 16 – ESQUEMÁTICO V4.3 (UART, GPIO Y ALIMENTACIÓN)

En la ilustración 17 se muestra el esquema de conexionado para el módulo hardware Bluetooth. En él se puede ver un divisor resistivo que adapta la tensión de las señales y le permite conectarse con el Arduino.

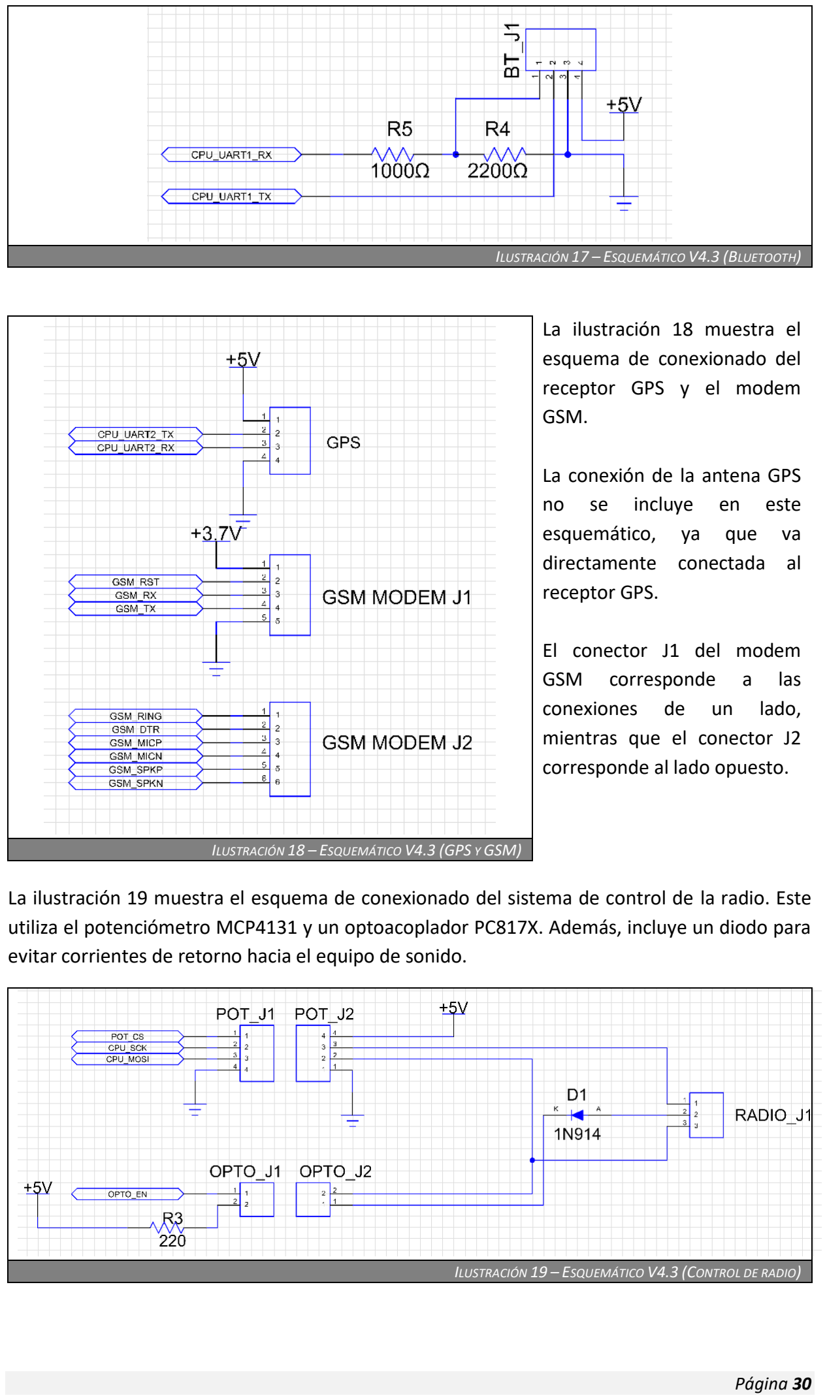
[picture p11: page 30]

ILUSTRACIÓN 17 – ESQUEMÁTICO V4.3 (BLUETOOTH)

La ilustración 18 muestra el esquema de conexionado del receptor GPS y el modem
GSM.

La conexión de la antena GPS
no | se | incluye | en | este
esquemático, ya que va
directamente conectada al
receptor GPS.

El conector J1 del modem
GSM | corresponde | a | las
conexiones | de | un | lado,
mientras que el conector J2 corresponde al lado opuesto.

ILUSTRACIÓN 18 – ESQUEMÁTICO V4.3 (GPS Y GSM)

La ilustración 19 muestra el esquema de conexionado del sistema de control de la radio. Este utiliza el potenciómetro MCP4131 y un optoacoplador PC817X. Además, incluye un diodo para evitar corrientes de retorno hacia el equipo de sonido.

ILUSTRACIÓN 19 – ESQUEMÁTICO V4.3 (CONTROL DE RADIO)

### 3.6 – PLACA BASE

Para garantizar la correcta interconexión de todos los componentes se ha diseñado una placa de circuito impreso (PCB). El diseño y la placa se pueden ver en las ilustraciones 20, 21 y 22. Debido al número de componentes y a su conexionado, la placa requiere pistas por ambas caras, lo que da lugar a un proceso de construcción un poco complejo y dificulta la construcción manual.

Distribución de componentes:
(De izquierda a derecha y de arriba a abajo)
- Amarillo: Bluetooth HC-05/HC-06.
- Azul oscuro: Arduino Nano V3.
- Salmón: Modem GSM SIM800L.
- Verde: GPS GY-NEO6MV2.
- Fucsia: CAN MCP2515.
- Marrón: Optoacoplador PC817.
- Aguamarina: Potenciómetro MCP4131.

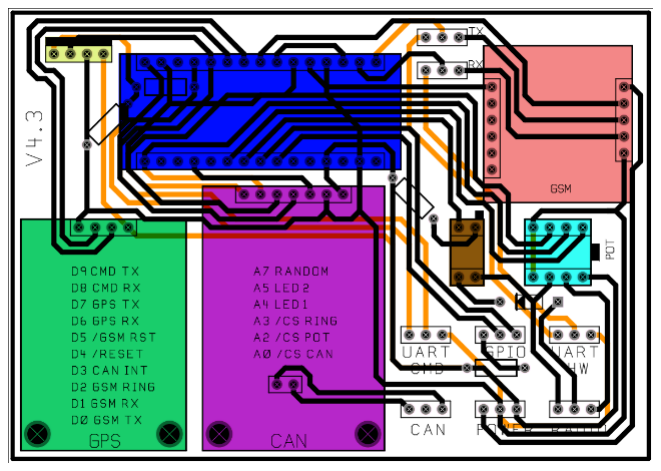
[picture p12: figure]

ILUSTRACIÓN 20 – DISTRIBUCIÓN DE COMPONENTES (PLACA V4.3)

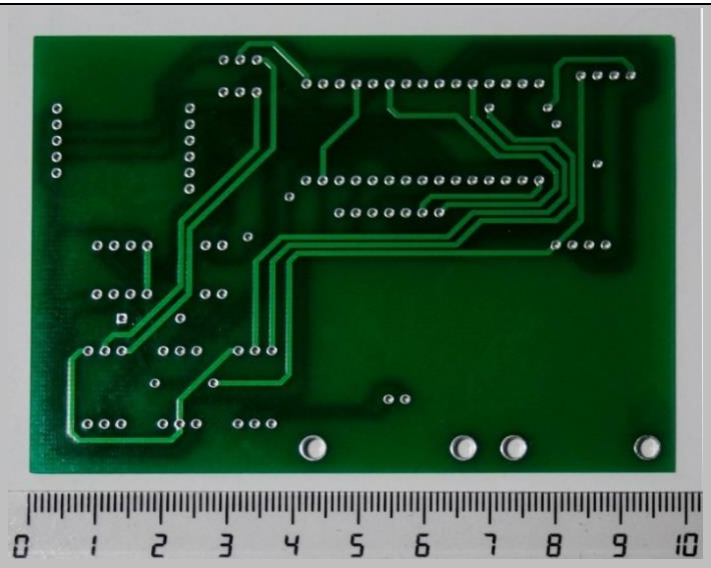
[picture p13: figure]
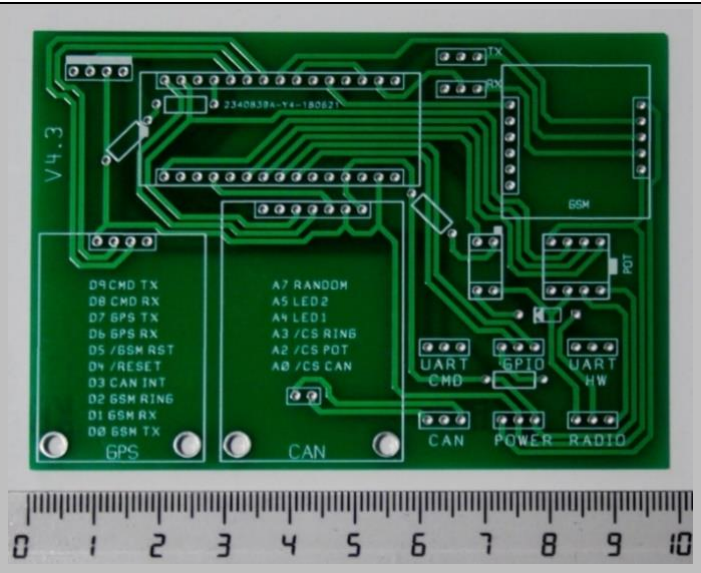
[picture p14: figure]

ILUSTRACIÓN 21 – PLACA V4.3 (FRONTAL) | ILUSTRACIÓN 22 – PLACA V4.3 (TRASERA)

El diseño de la placa se ha realizado mediante la utilidad PCB Web ³ debido a su reducida curva de aprendizaje. Resulta muy sencilla de utilizar y ofrece buenos resultados. Permite exportar el diseño en formato Gerber y de esta forma enviarlo a un fabricante.

En este caso se han fabricado con la compañía JLCPCB 4 debido a su relación entre precio, calidad del producto y velocidad de envío.

3 PCBWeb - http://www.pcbweb.com/

4
JLCPCB - https://jlcpcb.com/

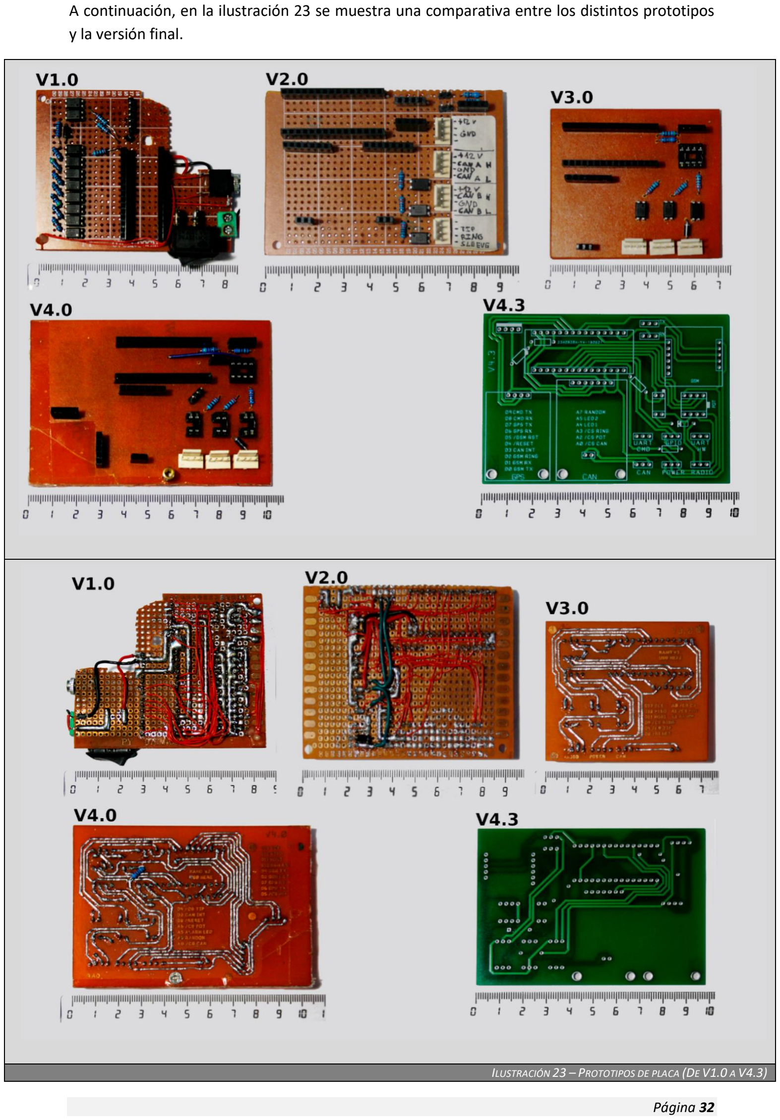
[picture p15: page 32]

A continuación, en la ilustración 23 se muestra una comparativa entre los distintos prototipos y la versión final.

ILUSTRACIÓN 23 – PROTOTIPOS DE PLACA (DE V1.0 A V4.3)

### 3.7 – MECANIZADO

Una vez está todo el circuito ensamblado es necesario encapsularlo de forma que sus contactos se queden aislados para poder instalarlo de forma segura en el automóvil y evitar posibles cortocircuitos, filtraciones de humedad, etc…

Se ha creado un modelo 3D de la carcasa con las medidas necesarias y los huecos de los conectores en sus posiciones exactas. Este modelo puede ser impreso mediante una impresora 3D o enviado a producir a un fabricante.

Existen multitud de herramientas de diseño CAD, tanto gratuitas, como de pago y en versiones online y offline.

Este modelo se ha llevado a cabo usando la herramienta online Tinkercad 5
. Esta herramienta
es muy sencilla y cómoda de utilizar, pues al ser online no es necesario instalar ninguna dependencia adicional y funciona desde cualquier equipo con un navegador web moderno y una conexión a internet.

Las ilustraciones 24 y 25 muestran el modelo del mecanizado (tanto la carcasa como la tapa).

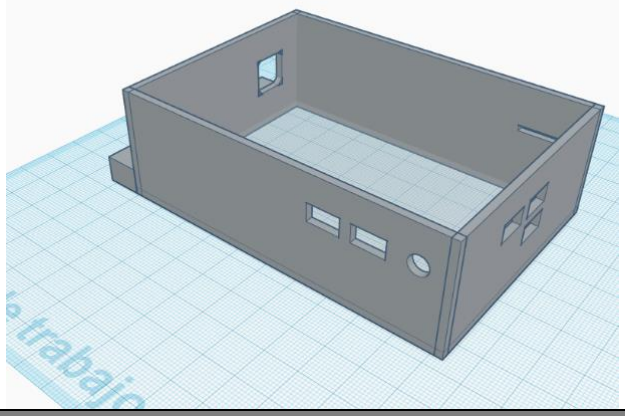
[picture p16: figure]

ILUSTRACIÓN 24 – VISTA DEL MECANIZADO (1)

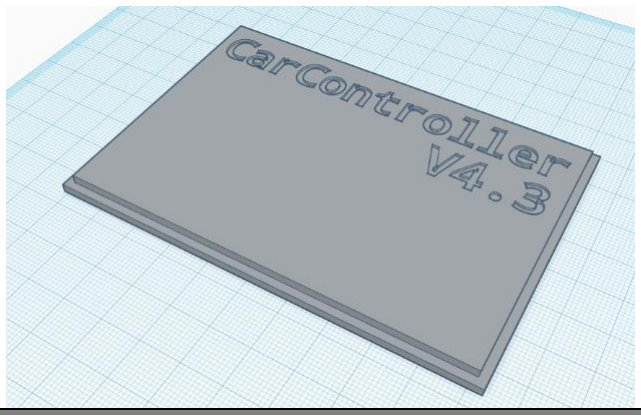
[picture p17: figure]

ILUSTRACIÓN 25 – VISTA DEL MECANIZADO (2)

5 Tinkercad - https://www.tinkercad.com/

La ilustración 26 muestra la controladora completamente ensamblada e introducida en el mecanizado.

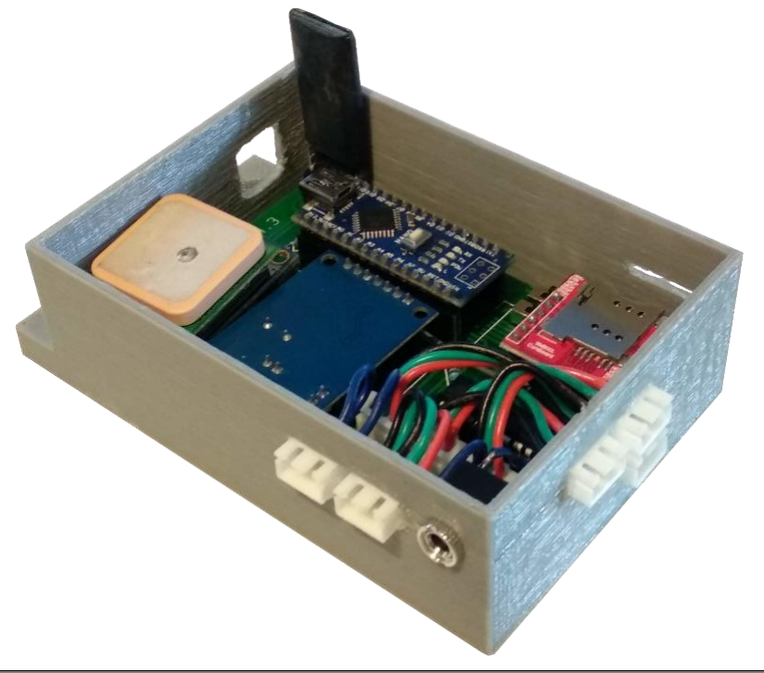
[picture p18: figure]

ILUSTRACIÓN 26 – VISTA DEL ENSAMBLADO COMPLETO

## 4 – DISEÑO E IMPLEMENTACIÓN SOFTWARE

En este apartado se presenta en detalle el diseño y la implementación del software. Este software se divide en tres partes, software del microcontrolador, software de control móvil y software de la plataforma de seguimiento.

Tanto el software del microcontrolador como el software de control móvil han sido desarrollados siguiendo un ciclo de vida en cascada y una metodología tradicional.

### 4.1 – SOFTWARE DEL MICROCONTROLADOR

Esta parte incluye el código específico para manejar el hardware citado en puntos anteriores y proporciona e implementa la mayor parte de las funcionalidades especificadas en los requisitos.

Este código se compila en base a una serie de parámetros directamente ligados con las funciones habilitadas y con el modelo del vehículo, dando lugar a un ejecutable binario que reside en la memoria del microprocesador y que será ejecutado una vez el sistema entre en funcionamiento.

### 4.1.1 – ENFOQUE SOBRE EL DESARROLLO

Para proveer al código fuente de portabilidad, seguridad y fiabilidad, se han cumplido las recomendaciones MISRA C (Motor Industry Software Reliability Association) [4] [7].

Como se ha indicado en los requisitos y también por las decisiones tomadas en el diseño de hardware, especialmente al elegir el Arduino Nano, el código debe mostrar un equilibrio entre eficiencia, consumo reducido de memoria RAM y un tamaño del ejecutable aceptable.

Como ejemplo, debido a que normalmente la memoria RAM de los sistemas microcontrolador es de un tamaño reducido, las cadenas de texto y los datos a los que no se accede frecuentemente se almacenan en la memoria Flash en lugar de la SRAM. En Arduino, a esta utilidad se le llama PROGMEM [11].

Esta opción resulta muy útil cuando se requiere de gran cantidad de datos incluidos en el programa sin que esto reduzca la memoria RAM disponible. No debemos olvidar que un acceso a memoria SRAM es casi instantáneo a lo que ciclos de ejecución se refiere y una lectura desde la memoria Flash puede llegar a ser cientos de veces más lenta, por lo que es importante reservar la memoria RAM para los datos que se usan con mayor frecuencia

Por otra parte, la modularidad en el desarrollo resulta crucial. La única forma de conseguir compatibilidad entre distintos vehículos es partiendo de una base mayoritariamente genérica e incluir pequeñas partes específicas para cada marca y modelo.

### 4.1.2 – ESTRUCTURA INTERNA

En la ilustración 27 se muestra un esquema de la estructura interna de los módulos software, las bibliotecas empleadas y los protocolos de comunicaciones empleados con los periféricos.

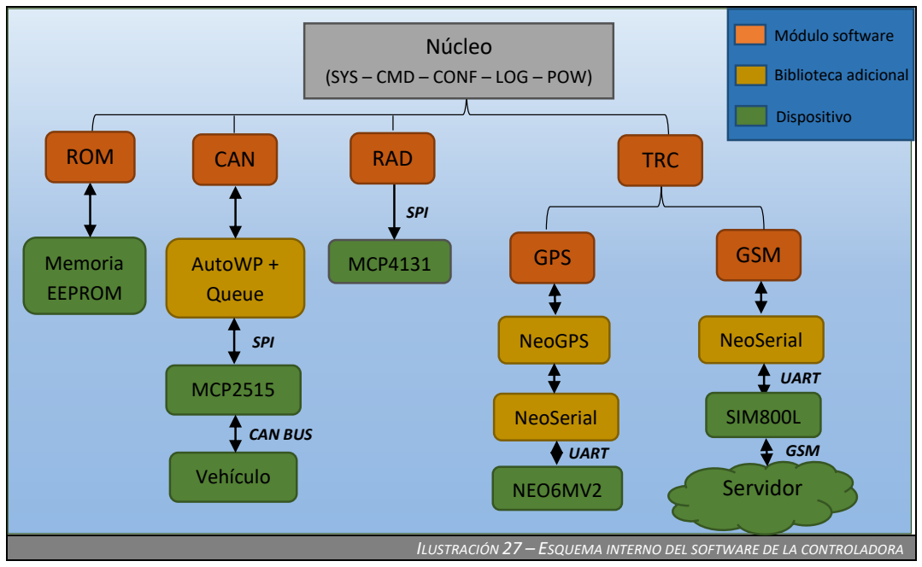
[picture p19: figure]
Memoria; GPS; GSM; EEPROM; Vehículo; AutoWP + Queue; MCP2515; MCP4131; NEO6MV2; Servidor; NeoGPS; NeoSerial; ROM; Núcleo; (SYS – CMD – CONF – LOG – POW); CAN; RAD; Módulo software; Biblioteca adicional; Dispositivo; CAN BUS; SPI; UART; SIM800L; TRC

ILUSTRACIÓN 27 – ESQUEMA INTERNO DEL SOFTWARE DE LA CONTROLADORA

### 4.1.3 – MÓDULOS SOFTWARE Y FUNCIONALIDADES

En este punto se detallan las distintas partes y módulos software implementados.

4.1.3.1 – NÚCLEO – GESTIÓN DEL SISTEMA

Este apartado describe el módulo principal del sistema, que es el responsable de dotar de unas funcionalidades básicas y jerarquizar el sistema empleando un sistema modular. Se puede dividir conceptualmente en distintas partes, aunque forman parte de un todo indivisible.

- | SYS | - | Sistema general y manejo de módulos.
- | CMD - | Sistema de manejo de eventos y acciones.
- | CONF - | Configuración de módulos en tiempo de ejecución.
- | LOG - | Sistema de registro de eventos y depuración.
- | POW - | Sistema de alimentación y control de energía.

En la tabla 1 se detallan los parámetros obligatorios en el fichero de configuración:
Parámetro | Descripción
CAR_MODEL | Indica el modelo del vehículo al que se va a conectar.
BOARD_VERSION | Indica la revisión de la placa base que se va a emplear. Es la forma de indicar la configuración de pines correcta.
DEFAULT_BAUDRATE | Tasa de baudios que emplea la interfaz serie principal.
SERIAL_CONTROL_MODE | Indica los manejadores de comandos que deben ser incluidos en el sistema en tiempo de compilación. - SC_FULL – Todos los módulos - SC_MID – Módulos básicos y utilidades. - SC_MIN – Módulos mínimos.
USE_STATIC_MEM | Indica si los módulos deben utilizar memoria estática o dinámica.
POW_ENABLE_WATCHDOG | Habilita el watchdog integrado en el sistema.
POW_WATCHDOG_TIMEOUT | Indica el tiempo que debe esperar el watchdog para actuar.

TABLA 1 – PARÁMETROS DEL NÚCLEO EN TIEMPO DE COMPILACIÓN

4.1.3.2 – ROM – CONFIGURACIÓN EN EEPROM

Resulta esencial en muchas circunstancias disponer de un soporte no volátil para almacenar información. En este caso se emplea una EEPROM donde guardar algunas configuraciones que pueden variarse en tiempo de ejecución.

Además de configuración, también incorpora un sencillo sistema de entradas indexadas donde cada módulo puede guardar los datos que considere sin que haya riesgo de solaparse con otros.

4.1.3.3 – CAN – COMUNICACIONES POR BUS

Este módulo es el encargado de gestionar todas las comunicaciones con el automóvil a través de la red CAN BUS. Es especialmente crítico ya que debe ser robusto y fiable, además de cumplir con unas restricciones temporales muy marcadas o en su defecto comenzaría a perder información y a causar errores en las comunicaciones.

Incluye un sistema de colas tanto para envío como para recepción, un sistema de interrupciones, listas blanca y negra y un sistema de envíos periódicos entre otros.

Para evitar confusiones, la unidad de información que se envía por CAN BUS se va a denominar “Mensaje” en adelante.

La lista blanca permite establecer desde qué identificadores CAN queremos recibir mensajes, de forma que el resto de mensajes se ignorarán. Por el contrario, la lista negra permite establecer qué identificadores queremos ignorar.

En la tabla 2 se detallan los parámetros referentes al módulo CAN.
Parámetro | Descripción
COMPILE_CAN | Habilita / Deshabilita el módulo CAN. Generalmente sólo se deshabilita por tareas de depuración.
COMPILE_CAN_PIN_CMD_AVAILABLE | Indica si la controladora CAN dispone de un pin conectado al GPIO de la CPU que indique si hay mensajes por recibir.
COMPILE_CAN_INTERRUPT | Habilita el sistema de interrupciones. En caso contrario utiliza un sistema de Polling.
COMPILE_CAN_WHITELIST | Habilita el sistema de “lista blanca”. Normalmente gestionado por la propia controladora.
COMPILE_CAN_BLACKLIST | Habilita el sistema de “lista negra”. En este caso es gestionado directamente por el módulo software.
COMPILE_CAN_PERIODICAL | Habilita el sistema de comandos periódicos. Permite establecer una serie de comandos que se enviarán periódicamente. Resulta útil en mensajes de difusión de estado y similares.
CAN_CLOCKSET | La frecuencia del oscilador conectado a la controladora. Frecuencias válidas: MCP_8MHZ, MCP_16MHZ, MCP_20MHZ
CAN_ENABLE_TX_QUEUE | Habilita la cola en los mensajes de salida.
CAN_RX_QUEUE_LENGTH | Indica el tamaño máximo de mensajes que puede haber en las colas de entrada o salida. En caso de excederse el sistema

registra el error y descarta los mensajes antiguos. CAN_TX_QUEUE_LENGTH

CAN_MIN_COMMAND_INTERVAL
(milisegundos)

El tiempo mínimo que debe trascurrir entre el envío de mensajes. Esto es necesario para evitar una posible saturación en el bus de datos.

CAN_INTERRUPT_MODE | Indica el modo en que funciona el sistema de interrupciones. Los modos disponibles son: -CAN_INTERRUPT_MODE_FETCH: La rutina de interrupción obtiene el mensaje directamente desde la controladora en el momento que llega. -CAN_INTERRUPT_MODE_FLAG: La rutina de interrupción habilita un flag para que se obtenga el mensaje fuera de la propia rutina.
CAN_TX_RETRY_TIMEOUT (milisegundos) | El tiempo que se espera para reintentar un envío fallido.

TABLA 2 – PARÁMETROS EN TIEMPO DE COMPILACIÓN DEL MÓDULO CAN

4.1.3.4 – RAD – CONTROL DE RADIO

Este módulo software se emplea para controlar equipos de sonido siguiendo el protocolo Wired/Remote.

Con la intención de facilitar el desarrollo, por cuestiones de diseño y de seguridad, este módulo enmascara las acciones de la radio de forma que el resto de módulos sólo pueden activar estas acciones y no deben indicar el valor específico de la resistencia para cada caso.

La tabla 3 muestra los parámetros de configuración del módulo software RAD.
Parámetro | Descripción
POT_SHOW_KOHMS | Habilita la visualización de los valores de la resistencia. Utilizado para tareas de depuración y desarrollo.
RADIO_COMMAND_MIN_INTERVAL | Definen el intervalo de tiempo (en milisegundos) que debe
RADIO_COMMAND_MAX_INTERVAL | mantenerse un único comando de la radio.
RADIO_USE_TIP_OPTOCOUPLERS | Indica si se utilizan optoacopladores externos para desconectar
| los terminales del potenciómetro o por el contrario se utiliza el
| mecanismo integrado en el propio potenciómetro.

TABLA 3 – PARÁMETROS EN TIEMPO DE COMPILACIÓN DEL MÓDULO POT

En la tabla 4 se muestran las distintas acciones y los valores de la resistencia asociados que se pueden emplear para controlar un equipo de sonido mediante el protocolo Wired/Remote. En caso de que el valor de la resistencia se encuentre fuera de estos rangos, el equipo de sonido simplemente ignorará la acción.

Acción | Valor de la resistencia (kΩ) | Puentea “Ring”
Mínimo | Nominal | Máximo
Origen / Apagar | 0.4 | 1.2 | 2 | No
Silenciar (ATT) | 2.5 | 3.5 | 4.5 | No
Display / Pantalla | 5 | 5.75 | 6.5 | No
Siguiente canción | 7 | 8 | 9 | No
Canción anterior | 9.5 | 11.25 | 13 | No
Subir volumen | 13.5 | 16 | 18.5 | No
Bajar volumen | 19 | 24 | 29 | No
Band / Escape | 37.5 | 62.75 | 88 | No
Subir carpeta | 7 | 8 | 9 | Sí
Bajar carpeta | 9.5 | 11.25 | 13 | Sí
Control por voz | 37.5 | 62.75 | 88 | Sí

TABLA 4 – RELACIÓN DE VALORES RESISTIVOS Y ACCIONES WIRED REMOTE

4.1.3.5 – GPS – SISTEMA DE POSICIONAMIENTO GLOBAL

La funcionalidad de geolocalización viene gestionada por este módulo, el cual encapsula toda la complejidad interna del sistema GPS y facilita su uso al resto del sistema. Su principal función es analizar los mensajes recibidos por el receptor GPS en el formato NMEA 0183 y convertirlos a estructuras de datos más manejables para los otros módulos.

Generalmente se utiliza en conjunción a los módulos GSM y TRC que se detallan a continuación, aunque puede utilizarse de forma independiente para, por ejemplo, obtener la hora UTC a través de los satélites GPS.

En la tabla 5 se pueden ver algunos parámetros de configuración de este módulo software.
Parámetro | Descripción
GPS_BAUDRATE | La tasa de baudios que emplea el receptor GPS. Sólo se utiliza en caso de UART.
GPS_SERIAL_ALWAYS_ENABLED | Indica si el receptor GPS siempre debe estar activado o por el contrario se activa por solicitud de algún módulos software.

TABLA 5 – PARÁMETROS EN TIEMPO DE COMPILACIÓN DEL MÓDULO GPS

4.1.3.6 – GSM – COMUNICACIONES POR RED MÓVIL

Este módulo gestiona toda la conectividad a internet del sistema. Es el encargado de comunicarse con el módulo GSM [1] (a través de comandos AT ⁶
), configurarlo, y manejar todas las solicitudes y respuestas mediante un sistema de eventos interno.

También permite establecer un servicio a la escucha para recibir comandos a través de internet, aunque esta característica no se recomienda por cuestiones de seguridad y está deshabilitada por defecto.

En la tabla 6 se detallan algunos parámetros en la configuración del módulo GSM.
Parámetro | Descripción
GSM_BAUDRATE | La tasa de baudios que emplea el módulo GSM. Sólo se utiliza en caso de UART.
GSM_GET_MAX_TIMEOUT | El tiempo máximo de espera para recibir la respuesta a una solicitud antes de darse por fallida.
GSM_SETUP_MAX_TIMEOUT | El tiempo máximo de espera al iniciar la controladora GSM y conectarse a la red móvil antes de un reinicio forzado.
GSM_DISABLE_LEDS | Deshabilita los LEDs incorporados en la placa del modem GSM.
GSM_USE_FLASH_STRINGS | Especifica si los comandos AT se almacenan en la memoria RAM o en la sección de código del programa (PROGMEM).
GSM_COMMAND_QUEUE_LENGTH | Indica el tamaño máximo de la cola donde se almacenan los comandos AT pendientes de procesar.
GSM_APN | Indica el parámetro APN que se utiliza en la conexión.
GSM_PIN | Indica el código secreto de la tarjeta SIM.

TABLA 6 – PARÁMETROS EN TIEMPO DE COMPILACIÓN DEL MÓDULO GSM

6 Comandos AT - https://es.wikipedia.org/wiki/Conjunto_de_comandos_Hayes

4.1.3.7 – TRC – TRACCAR – PLATAFORMA DE SEGUIMIENTO

Este módulo software requiere a su vez de los módulos GPS y GSM para su funcionamiento. Se centra en tomar las posiciones obtenidas por el módulo GPS y en base a ellas, formar las solicitudes con el formato correcto del servicio Traccar para enviarlas a través de la red empleando el módulo GSM.

Además de la posición también puede enviar mediciones sobre el estado del vehículo en tiempo real como la posición del contacto, el voltaje de la batería o la velocidad a la que está circulando.

A continuación, en la tabla 7, se muestran algunos parámetros de configuración.
Parámetro | Descripción
TRACCAR_NOTIFICATION_INTERVAL_ON | Indica el intervalo de notificaciones. Se pueden especificar tiempos diferentes dependiendo de si el

automóvil está encendido o no. TRACCAR_NOTIFICATION_INTERVAL_OFF

TRACCAR_SEND_TIMESTAMP | Indica si se envía la fecha y la hora con cada notificación.
TRACCAR_MAX_REQUEST_RETRIES | Especifica el número máximo de reintentos al reenviar una notificación fallida antes de descartarla.
TRACCAR_NOTIFICATION_QUEUE_LENGTH | Indica el tamaño máximo de la cola donde se almacenan las notificaciones.
TRACCAR_HOST | El nombre de host donde se encuentra el servicio Traccar en funcionamiento.
TRACCAR_PORT | El puerto donde está el servicio Traccar a la escucha.
TRACCAR_DEVICE_ID | El identificador único del dispositivo. Este valor se configura en el servidor y generalmente es un texto.

TABLA 7 – PARÁMETROS EN TIEMPO DE COMPILACIÓN DEL MÓDULO TRC

### 4.1.4 – BIBLIOTECAS ADICIONALES

En la tabla 8 se pueden ver varias bibliotecas que se han empleado durante el desarrollo.
Nombre | Autor | Página oficial
Arduino MCP2515 CAN interface library | AutoWP | https://github.com/autowp/arduino-mcp2515
Biblioteca para el componente MCP2515.

NeoGPS

Slash Devin https://github.com/SlashDevin/NeoGPS Biblioteca eficiente para la gestión de sentencias NMEA 0183.

FastGPIO

Pololu | https://github.com/pololu/fastgpio-arduino
Gestión rápida de pines de entrada y salida.

Queue

SMFSW https://github.com/SMFSW/Queue Estructuras de colas FIFO y LIFO.

NeoHWSerial

Slash Devin https://github.com/SlashDevin/NeoHWSerial Ampliación de la clase “Serial” con más funcionalidades.

NeoSWSerial

Slash Devin https://github.com/SlashDevin/NeoSWSerial Reemplazo eficiente de la clase “SoftwareSerial”

NeoICSerial

Slash Devin https://github.com/SlashDevin/NeoICSerial Comunicaciones UART usando los pines “Input Capture”.

TABLA 8 – BIBLIOTECAS EMPLEADAS EN EL DESARROLLO

### 4.1.5 – HERRAMIENTAS DE DESARROLLO

Para llevar a cabo el desarrollo del software del microcontrolador se han empleado distintas herramientas.

Para compilar código compatible con la amplia gama de modelos de Arduino es necesario tener instalado el entorno oficial del Arduino. Este kit incluye un editor muy sencillo para crear los programas (conocidos como sketches), pero a medida que el proyecto crece y aumenta de tamaño se vuelve tedioso y poco práctico.

Por ello se ha empleado principalmente la utilidad Visual Studio 2017 de Microsoft, la cual proporciona un entorno de desarrollo muy completo para gran cantidad de plataformas como Windows, Windows IoT, Web (ASP.Net, MVC), e incluso móvil con Xamarin.

Aunque no soporta la plataforma Arduino de forma oficial, existe un plugin llamado Visual Micro⁷ que añade el soporte y todos los recursos necesarios para llevar a cabo un desarrollo completo.

Para la gestión del código se ha utilizado un repositorio subversión, el cual ha sido gestionado por otro plugin llamado AnkhSVN 8
. Aunque el uso de un repositorio de código para un desarrollo individual pueda parecer excesivo, resultan de gran ayuda las características que ofrece este servicio. Características como el histórico de cambios, la posibilidad de crear distintas “ramas” o tener el código centralizado para, por ejemplo, crear copias de seguridad fácilmente, lo hacen una herramienta indispensable.

### 4.1.6 – PROTOCOLO DE COMUNICACIONES INTERNO

El núcleo procesa los comandos recibidos por el puerto serie. Estos comandos permiten gestionar las opciones en tiempo de ejecución o pueden están asociados a acciones del propio núcleo o de los módulos software. La especificación de estos comandos es crucial, ya que son la interfaz que va a permitir al usuario interactuar con el sistema y al resto de módulos entre sí.

Los comandos se crean en formato texto y cuentan con una sintaxis muy similar a una llamada a función en lenguaje C, aunque con ligeras variaciones.

Cada comando está compuesto por una parte que indica un prefijo, una función y una serie de parámetros variables separados por el carácter ‘;’.

En la tabla 9 se muestra la sintaxis de los comandos.
Sintaxis BNF (Backus-Naur)

<comando> ::= <prefijo>:<función>([{<Parámetro>};]);

Ejemplos:
- | SYS:free(); | • | LOG:set(CAN;1);
- | CAN:send(0x203;0x01;0x20;0x94); | • | POW:on();

TABLA 9 – SINTAXIS BNF DE LOS COMANDOS DE CONFIGURACIÓN

7 Visual Micro - https://www.visualmicro.com/8 AnkhSVN - https://ankhsvn.open.collab.net/

Los manejadores de los comandos pueden ser sobrescritos para ampliar su funcionalidad desde otro módulo. Es decir, un comando puede ser ampliado con más funciones desde distintos módulos software.

4.1.6.1 – ACCIONES IMPLEMENTADAS

En las tablas 10 a 16 se detallan las acciones incluidas en la base del proyecto. En la implementación del vehículo es posible añadir más acciones, pero estas deben ser específicas para el modelo del automóvil.

Núcleo – Prefijo SYS
Función | Parámetros | Descripción
free | - | Devuelve la cantidad de memoria RAM libre (en bytes)
reset | - | Reinicia el sistema.

TABLA 10 – ACCIONES – FUNCIONES DEL NÚCLEO – SYS

Núcleo – Prefijo OPT
Función | Parámetros | Descripción
get | 1. Nombre del módulo | Obtiene o establece si se debe activar un módulo específico. Módulos válidos: • TRC – Traccar
set | 1. Nombre del módulo 2. Valor

TABLA 11 – ACCIONES – FUNCIONES DEL NÚCLEO – OPT

Núcleo – Prefijo LOG
Función | Parámetros | Descripción
get | 1. Nombre del registro | Obtiene o establece si se debe mostrar un registro específico. Registros válidos: • CAN – CAN BUS • POT – Potenciómetro • STA – Estado • TRC – Traccar • GSM – Acceso a internet • GPS – Geolocalización • DBG – Depuración / Desarrollo
set | 1. Nombre del registro 2. Valor

TABLA 12 – ACCIONES – FUNCIONES DEL NÚCLEO – LOG

Núcleo – Prefijo POW
Función | Parámetros | Descripción
on | - | Cambia al modo de vehículo encendido.
off | - | Cambia al modo de vehículo apagado.

TABLA 13 – ACCIONES – FUNCIONES DEL NÚCLEO – POW

Módulo – Prefijo ROM
Función | Parámetros | Descripción
save | - | Guarda la configuración actual en la memoria.
load | - | Carga la configuración desde la memoria.
clear | - | Borra toda la configuración de la memoria.
remove | 1. Índice de la entrada | Borra la entrada especificada de la memoria.
show | - | Muestra todas las entradas de la memoria.

TABLA 14 – ACCIONES – FUNCIONES DEL MÓDULO – ROM

Módulo – Prefijo RAD
Función | Parámetros | Descripción
vol+ | - | Subir volumen.
vol- | - | Bajar volumen.
next | - | Siguiente canción
prev | - | Canción anterior
dis | - | Alternar pantalla entre ecualizador, pista actual y reloj.
mute | - | Silenciar. (Modo ATT)
src | - | Alternar la fuente entre USB, Bluetooth, Radio o Auxiliar.
band | - | Función band.
f_up | - | Subir carpeta en el árbol de directorios.
f_down | - | Bajar carpeta en el árbol de directorios.
voice | - | Activar el control por voz.

TABLA 15 – ACCIONES – FUNCIONES DEL MÓDULO – RAD

Módulo – Prefijo CAN
Función | Parámetros | Descripción
send | 1. ID del mensaje 2. Contenido del mensaje (hasta 8 bytes) | Envía un mensaje por el bus de datos CAN.

TABLA 16 – ACCIONES – FUNCIONES DEL MÓDULO – CAN

### 4.2 – SOFTWARE DE CONTROL – APLICACIÓN MÓVIL / TABLET

Para gestionar la controladora es posible conectarse a ella utilizando el protocolo UART con un ordenador y mandar los comandos pertinentes. Claramente esto resulta muy farragoso además de poco intuitivo si no se tiene costumbre con la sintaxis y el nombre de las opciones.

Con la intención de facilitar las tareas de uso, configuración y depuración se ha creado un aplicativo para teléfonos móviles y tablets, que permite conectarse a la controladora y gestionarla de forma inalámbrica usando la conectividad Bluetooth. Este aplicativo funciona bajo el sistema operativo Android [2] (se puede ver el icono oficial en la ilustración 28) con la versión 4.4 o superior.

ILUSTRACIÓN 28 –
ICONO OFICIAL DE
ANDROID

Implementa la llamada a todas las acciones registradas en la controladora. Tanto las que se han comentado anteriormente como las específicas del automóvil en el que se han realizado las pruebas.

El diseño de la interfaz gráfica se ha centrado en crear una aplicación sencilla, práctica y que permita un acceso rápido a todas sus funciones con pocas pulsaciones.

### 4.2.1 – HERRAMIENTAS DE DESARROLLO

Se ha desarrollado con la herramienta oficial Android Studio (se puede ver el icono en la ilustración 29), creada de la mano de Google Inc. Es un IDE muy completo y especialmente diseñado para el desarrollo de aplicaciones nativas en Android.

Se integra completamente con todo el kit de desarrollo de Android, lo que permite, entre otras cosas, la creación de máquinas virtuales para probar las aplicaciones en múltiples versiones del sistema operativo o con distintos tamaños y relaciones de aspecto de la pantalla.

### 4.2.2 – IMÁGENES DE LA APLICACIÓN

En las ilustraciones 30, 31, 32 y 33 se puede ver el menú principal de la aplicación donde se encuentran múltiples controles como botones y selectores, los cuales se emplean para enviar acciones y modificar distintas configuraciones del sistema.

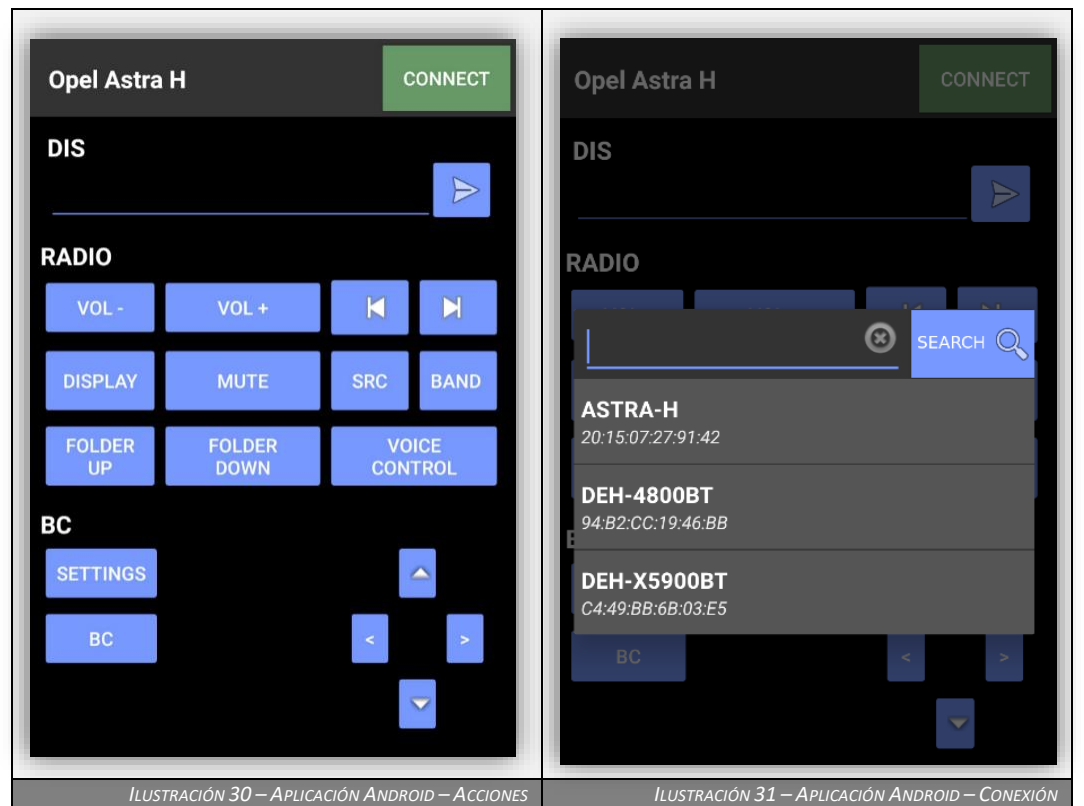
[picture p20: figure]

ILUSTRACIÓN 30 – APLICACIÓN ANDROID – ACCIONES | ILUSTRACIÓN 31 – APLICACIÓN ANDROID – CONEXIÓN

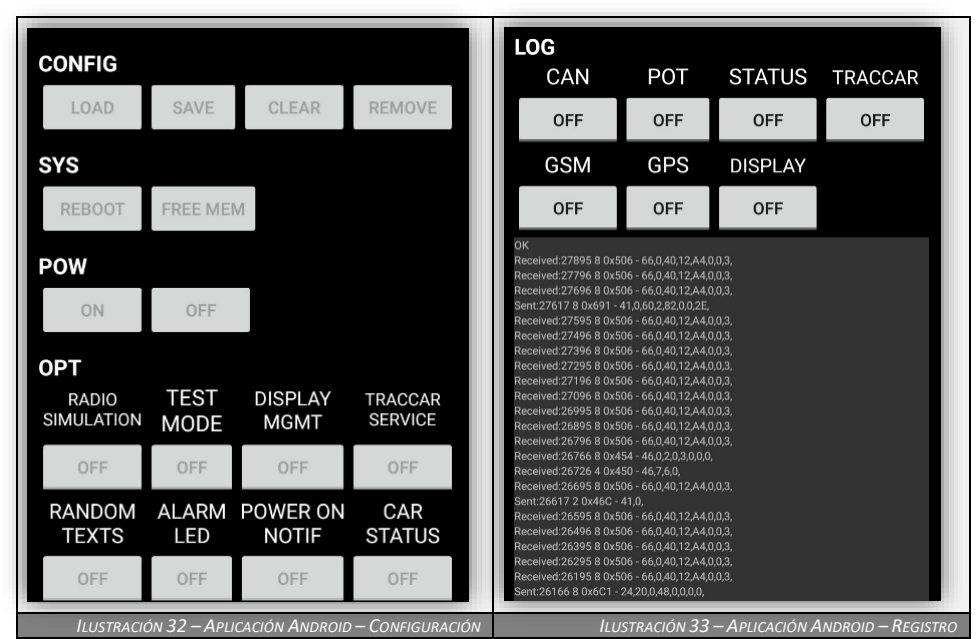
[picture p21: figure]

ILUSTRACIÓN 32 – APLICACIÓN ANDROID – CONFIGURACIÓN | ILUSTRACIÓN 33 – APLICACIÓN ANDROID – REGISTRO

### 4.3 – SOFTWARE DE SEGUIMIENTO – PLATAFORMA TRACCAR

Como se ha visto en puntos anteriores, la controladora se encarga de obtener la posición desde el módulo hardware GPS, transformarla al formato correcto y enviarla por internet hasta un servidor.

Este servidor ejecuta una plataforma de seguimiento
llamada Traccar (ver ilustración 34), la cual gestiona todas
las solicitudes y añade gran cantidad de funcionalidades como alarmas, histórico de posiciones, geocercas, etc…

Traccar es un proyecto de software libre desarrollado y administrado por la compañía Traccar Ltd residente en San Petersburgo.

El modelo de negocio que sigue esta compañía se basa en ofrecer su plataforma como un servicio bajo un pago recurrente mensual. Pero la plataforma en sí es gratuita y está disponible para descargarla y ejecutarla en un servidor propio sin coste alguno.

Soporta prácticamente la totalidad de dispositivos GPS comerciales de rastreo para todo tipo de vehículos e incluso terminales móviles o mascotas.

La monitorización se realiza mediante una interfaz web
(la cual se puede ver en la ilustración 35) que permite
gestionar todos los dispositivos con pocas pulsaciones.

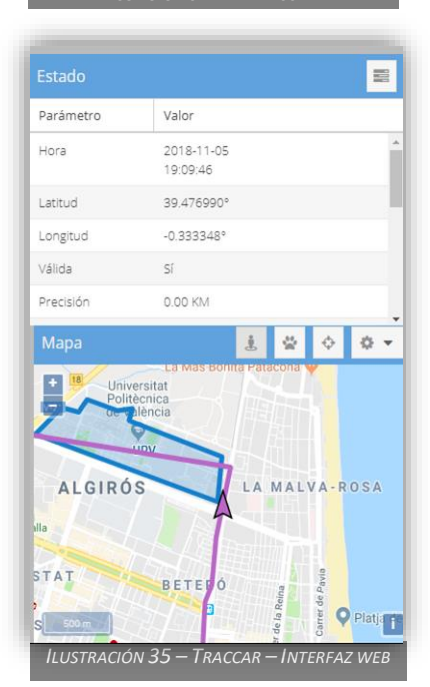
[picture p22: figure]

Es posible configurar alertas de velocidad, de encendido ILUSTRACIÓN 35 – TRACCAR – INTERFAZ WEB

ILUSTRACIÓN 34 –
ICONO OFICIAL DE TRACCAR y desconexión, delimitar zonas seguras, etc…

Además de la interfaz web, existe un aplicativo móvil (para Android e iOS) que permite acceder al panel de administración directamente sin necesidad de un navegador web.

En el caso de este proyecto se ha optado por la opción de instalar la plataforma de seguimiento bajo un servidor propio debido a la posibilidad de acceder directamente a las configuraciones y comprobar de primera mano los aspectos internos de la tecnología empleada.

En el caso de disponer de múltiples dispositivos y tener que realizar un seguimiento de todos, es preferible tomar la opción de pago ofrecida por la empresa para evitar tareas de mantenimiento y problemas derivados del servidor.

### 4.3.1 – CONFIGURACIÓN

Los parámetros por defecto que se especifican tras la instalación suelen ser suficientes para utilizar el servicio sin problemas. Aunque hay varios parámetros útiles que no son directamente configurables desde el panel de administración web, y deben ser escritos de forma manual en el fichero de configuración “conf/traccar.xml”. Algunos parámetros interesantes se pueden ver en la tabla 17.

Nombre | Tipo | Descripción
database.driver | Cadena de texto | Permite especificar el driver que se empleará para conectar a la base de datos.
database.url | Cadena de texto | La ruta a la base de datos.
database.user | Cadena de texto | Usuario de la base de datos.
database.password | Cadena de texto | Clave de acceso a la base de datos.
filter.enable | Booleano | Habilita el filtrado de posiciones.
filter.invalid | Booleano | Filtra las posiciones marcadas como inválidas.
filter.zero | Booleano | Filtra las posiciones en el punto (0,0).
filter.future | Número entero | Para una posición recibida, indica cuantos segundos puede estar en el futuro.
status.timeout | Número entero | Indica el número de segundos de inactividad antes de que el dispositivo se marque como desconectado.
processing.remoteAddress.enable | Booleano | Indica si se almacena la dirección IP con cada posición recibida.
mail.smtp.host | Cadena de texto | Indica el host del servidor de correo.
mail.smtp.port | Número entero | Indica el puerto del servidor de correo.
mail.smtp.starttls.enable | Booleano | Habilita el uso de la tecnología StartTLS.
mail.smtp.from | Cadena de texto | Indica la dirección de correo saliente.
mail.smtp.auth | Booleano | Indica si se utiliza autenticación en el servidor.
mail.smtp.username | Cadena de texto | Indica el nombre de usuario y la contraseña en el servidor de correo
mail.smtp.password | Cadena de texto

TABLA 17 – TRACCAR – CONFIGURACIÓN
Existen más parámetros compatibles en la web oficial ⁹ .

9
Fichero de configuración de Traccar - https://www.traccar.org/configuration-file/

## 4.3.2 – STUNNEL

Uno de los mayores inconvenientes de utilizar esta plataforma es que el servicio no incorpora el protocolo HTTPS (HTTP seguro) de forma nativa. Hoy en día es una característica imprescindible por motivos de seguridad. Más todavía si tenemos en cuenta que para acceder al panel de administración se envía un usuario y una contraseña sin cifrar por la red.

De forma opcional (aunque altamente recomendable) se puede emplear la utilidad STunnel para añadir la capa de seguridad de la que carece. Este programa encapsula todo el tráfico dirigido al servicio Traccar y lo envía a través de un canal seguro utilizando la tecnología SSL. De esta forma, el contenido inseguro nunca sale del servidor.

A continuación, en la ilustración 36 se muestra un ejemplo del funcionamiento de STunnel.

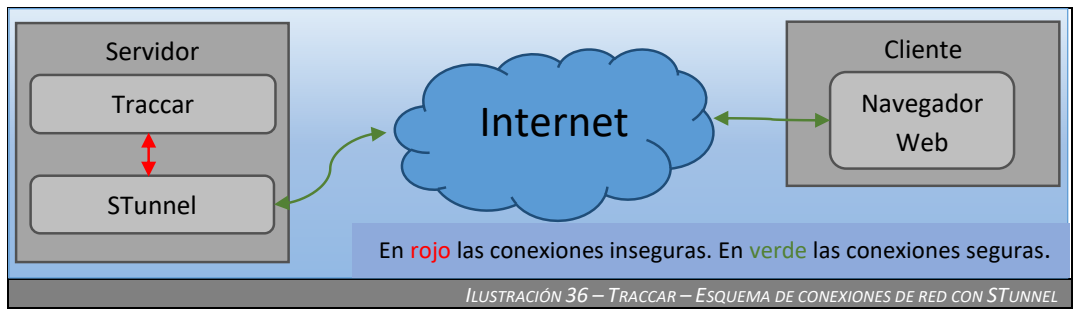
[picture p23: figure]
Servidor; Traccar; STunnel; Cliente; Navegador Web Internet

ILUSTRACIÓN 36 – TRACCAR – ESQUEMA DE CONEXIONES DE RED CON STUNNEL

Para utilizar este programa necesitamos crear un certificado con su clave privada correspondiente. Para ello podemos utilizar el comando “openssl” descrito en la tabla 18.

Sin Passphrase : openssl req -new -x509 -nodes -keyout server.pem -out server.pem Con Passphrase : openssl req -new -x509 -keyout user.pem -out user.pem

TABLA 18 – TRACCAR – CREACIÓN DE CERTIFICADOS MEDIANTE LA UTILIDAD OPENSSL

Para configurar STunnel es necesario escribir la configuración presentada en la tabla 19 dentro de un fichero de texto.

cert = server.pem
pid =
[TRACCAR]
accept = 8083
connect = localhost:8082

Explicación simplificada:
Utilizando el certificado “server.pem”, establecemos que STunnel se ponga a la escucha de forma segura en el puerto 8083 y redirija todo el tráfico al mismo servidor en el puerto 8082.

TABLA 19 – TRACCAR – FICHERO DE CONFIGURACIÓN DE STUNNEL

Este fichero de configuración es el mínimo necesario, aunque la herramienta cuenta con un gran número de opciones y funciones. Toda la información está disponible en la página oficial¹⁰

### 4.3.3 – PROTOCOLO OSMAND

Además de contar con compatibilidad para más de 170 protocolos comerciales y 1500 dispositivos de seguimiento GPS, Traccar incluye un protocolo propio llamado OsmAnd.

10 Página oficial de STunnel – https://www.stunnel.org/config_unix.html

En rojo las conexiones inseguras. En verde las conexiones seguras.

Este protocolo es muy sencillo y se basa en el ampliamente conocido estándar HTTP, aunque de forma predeterminada se encuentra a la escucha en el puerto TCP 5055.

Simplemente hay que realizar una solicitud GET al puerto especificado con los parámetros descritos en la tabla 20 en la URL:

Parámetro | Tipo | Obligatorio | Descripción
id / deviceid | Cadena de texto | Sí | El identificador del dispositivo.
valid | Booleano | No | Si la posición se asume como válida o no. Por defecto se asume lo que se indique en el fichero de configuración.
timestamp | Número entero | No | La fecha y la hora correspondiente a la posición en formato Unix Timestamp. Si no se indica en la solicitud, se toma la hora del servidor en el momento de la recepción.
lat | Número decimal | Sí | La latitud y la longitud de la posición.
lon | Número decimal | Sí
speed | Número decimal | No | La velocidad y altitud del dispositivo en el momento de tomar la posición. Por defecto se
| Número decimal | No | asume 0. altitude
batt | Número decimal | No | La carga de la batería del dispositivo. Al ser un número decimal se puede indicar un porcentaje o el voltaje de la misma.
cell | Tupla de números enteros | No | Una tupla de varios valores indicando los identificadores de la celda GSM a la que está conectado. Resulta útil para la geolocalización por antenas de telefonía.

TABLA 20 – TRACCAR – PARÁMETROS DEL PROTOCOLO OSMAND

Ejemplos:
http://<hostTraccar>:5055/?id=ABC&lat=39.482832&lon=-0.347319&speed=31.2&batt=49.3http://<hostTraccar>:5055/?id=DEF&lat=39.982182&lon=-0.748895&timestamp=1550582433

Se puede ver el listado completo de parámetros en el código fuente¹¹ de la clase OsmAndProtocolDecoder (archivo traccar/src/org/Traccar/protocol/OsmAndProtocolDecoder.java).

Los parámetros adicionales que no están establecidos en ese fichero se guardan como parámetros genéricos en una estructura de tipo “Clave-Valor”. Posteriormente pueden visualizarse o utilizarse como filtrado en el histórico de posiciones de la interfaz web.

11 GitHub de Traccar – https://github.com/traccar

## 5 – ESPECIFICACIÓN Y ADAPTACIÓN DE VEHÍCULOS

Acorde al paradigma modular empleado, es necesario establecer una especificación para cada modelo de vehículo distinto. Esta especificación es, a grandes rasgos, la parte de software que se encuentra más próxima al vehículo y a sus protocolos internos.

Esta parte es especialmente compleja debido a que generalmente los protocolos internos de comunicaciones no están documentados para el público general. Esto desencadena en que prácticamente la única forma de obtener esta información es capturando los datos del vehículo en durante su funcionamiento y analizarlos aplicando técnicas de ingeniería inversa.

### 5.1 – ESQUEMA BÁSICO PARA DEFINIR UN VEHÍCULO

Cada modelo de automóvil tiene sus particularidades, por lo que es necesario realizar una especificación cambiando ciertos parámetros de configuración. En algunas ocasiones incluso puede ser necesario añadir código específico para facilitar la integración con el automóvil.

El proyecto cuenta con una estructura de carpetas donde se ubican los ficheros dedicados para cada modelo de automóvil. Estos son los pasos a seguir para crear una especificación nueva:

- Dentro de la carpeta “cars/" se crea una carpeta con un nombre significativo de la marca y modelo del vehículo. Dentro de esta carpeta se deben incluir todos los ficheros necesarios para la implementación del modelo de vehículo.
- Los únicos ficheros obligatorios son:
- car_configuration.h – En este fichero van las configuraciones específicas del vehículo como por ejemplo los parámetros básicos del CAN BUS entre otros.
- main.c – El código que recibirá los eventos del sistema. Estos eventos están descritos en la tabla 21.
Función / Evento | Descripción
void carAfterMsgReceived( CAN_CONTROLLER *can, CAN_COMMAND *receivedMsg) | Este evento se dispara con la recepción de un mensaje en la controladora CAN. Como parámetros recibe la controladora que recibió el mensaje además del mensaje.
void carAfterLoop() | Este evento se dispara tras cada iteración del programa principal.
void carBeforeSetup() | Este evento se dispara antes de comenzar la configuración del sistema.
void carAfterSetup() | Este evento se dispara tras configurar todo el sistema.

TABLA 21 – ESPECIFICACIÓN DE VEHÍCULOS – EVENTOS
- Para que el compilador acceda a la nueva especificación es necesario editar el fichero “configuration.h” y añadir al final del mismo la referencia a la configuración anterior. Se puede ver un ejemplo en la tabla 22.

#if(CAR_MODEL == OPEL_ASTRA_H_2004_CAR)

#include "cars/OpelAstraH2004/car_configuration.h" #elif(CAR_MODEL == FORD_FOCUS_2004_CAR)

#include "cars/FordFocus2004/car_configuration.h" #else

#include "cars/DefaultCar/car_configuration.h" #endif

TABLA 22 – ESPECIFICACIÓN DE VEHÍCULOS – FICHERO DE CONFIGURACIÓN

### 5.2 – CASO ESPECÍFICO – OPEL ASTRA H

### 5.2.1 – BREVE RESUMEN SOBRE EL VEHÍCULO

El Opel Astra es un automóvil diseñado por el fabricante alemán de automóviles Opel y vendido en numerosos países bajo las marcas Vauxhall, Chevrolet y todas del grupo industrial estadounidense General Motors. Se puede ver el aspecto del automóvil en la ilustración 37.

En las últimas tres décadas se han lanzado cinco generaciones de este modelo. Cada una se denomina por una letra en orden alfabético. Las letras empleadas son F, G, H, J y K.

Este documento recoge información sobre la tercera generación (H), lanzada en el año 2004 y que permaneció en el mercado hasta finales del año 2010.

Esta generación marcó un punto de inflexión a nivel electrónico, ya que fue la primera en incorporar una gran cantidad de microcontroladores repartidos por el vehículo, desplazando la mayoría de los controles mecánicos tradicionales. Esto le permitió añadir sistemas más robustos e inteligentes como el control de estabilidad (ESP) o el control de velocidad de crucero y así obtuvo la certificación de cinco estrellas Euro NCAP 12 en la categoría de seguridad para ocupantes.

## 5.2.2 – CABLEADO

Aunque esta sección es específica del Opel Astra H, la información recogida a continuación es muy similar para todos los vehículos automóvil.

Para conectar la controladora genérica que se recoge en este documento es necesario conocer y modificar el cableado del vehículo [12] [17]. Es recomendable que dicha modificación la realice un profesional con los conocimientos necesarios para ello. Un conexionado incorrecto puede causar daños severos en los componentes del vehículo.

Los cables necesarios son:
- +12V – Alimentación – Se puede conectar directamente a la batería.
También se puede emplear la alimentación del contacto (12V IGN) para que la controladora sólo funcione con el automóvil encendido. Ambos se pueden encontrar en la caja de fusibles o más fácilmente en el conector del mechero de la consola central [6].
- GND – Masa – Se encuentra en muchas partes del vehículo. Incluso la propia carrocería está conectada a masa.
- CAN Low – Bus de datos CAN – Cable Low.
- CAN High – Bus de datos Can – Cable High.

En el caso del Opel Astra H resulta sencillo obtener todas conexiones anteriores del conector de la radio. Es recomendable comprar algún adaptador o alargador y así realizar las conexiones sobre éste y no realizar ninguna modificación o corte al cableado original. Se puede ver un adaptador en la ilustración 38 y el esquema de conexiones en la ilustración 39.

12 Euro NCAP – https://www.euroncap.com/es

ILUSTRACIÓN 37 – OPEL ASTRA H

ILUSTRACIÓN 38 – ADAPTADOR PARA LA RADIO ORIGINAL | ILUSTRACIÓN 39 – PINES DE LA RADIO ORIGINAL (CD30)

### 5.2.3 – BUS DE DATOS

Este automóvil cuenta con tres buses de datos distintos para gestionar todas las comunicaciones entre los dispositivos internos:

- Bus de alta velocidad HS-CAN – Este bus funciona a 500 Kbits/s y se emplea para las comunicaciones del bloque del motor. Por aquí viaja información como la velocidad del vehículo, temperatura del refrigerante, la marcha colocada o la activación del ABS.
- Bus de media velocidad MS-CAN – Este bus funciona a 95 Kbits/s. Este bus se emplea solamente para las comunicaciones entre los sistemas de entretenimiento y el aire acondicionado.
- Bus de baja velocidad LW-CAN – Este bus funciona a 33 KBits/s. Se utiliza para la comunicación del resto de sistemas auxiliares como puertas, luces o control de retrovisores.

El bus utilizado en esta controladora es el de media velocidad (MS-CAN). El principal motivo de esta elección es por razones de seguridad, ya que, en caso de fallo, los sistemas críticos no se ven afectados.

Algunos
componentes:
- Pantalla (DIS)
- Radio (EHU)
- Aire acondicionado
- Controladora de
iluminación trasera
(REC)
- Volante (CIM)
- Conector de
diagnóstico

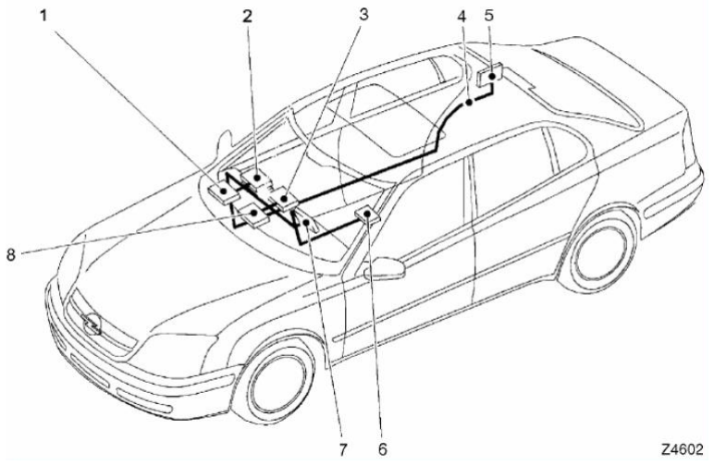
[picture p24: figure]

•

ILUSTRACIÓN 40 – ESQUEMA MS-CAN DEL OPEL ASTRA H

La ilustración 40 muestra algunos de los componentes que están conectados al MS-CAN y donde se encuentran ubicados. Es prácticamente la única información pública disponible acerca del bus de datos del Opel Astra H [9]. Se encuentra en un manual creado exclusivamente para los talleres autorizados de la marca.

La controladora puede conectarse en cualquier parte del bus de datos, aunque se ha decidido colocarla en la guantera o bajo la tapa del freno de mano por su facilidad de acceso y proximidad al conector de diagnóstico.

### 5.2.4 – COMPONENTES DEL VEHÍCULO

En la ilustración 34 se han citado distintos componentes del vehículo y su distribución por el interior del automóvil. En este punto vamos a ver en detalle qué funciones tienen los componentes principales [6].

5.2.4.1 – DIS –PANTALLA ORIGINAL

DIS (de Display o Pantalla) es el nombre que recibe este componente, el cual está formado por una unidad controladora y una pantalla para mostrar información. Dependiendo del año del vehículo y la gama seleccionada existen cuatro modelos distintos de la pantalla, los cuales están descritos en la tabla 23.

Nombre | Descripción
TID – Triple Info Display (Ilustración 41) | • Este modelo no llegó a comercializarse en España y sólo se incluyó en los primeros modelos vendidos de la marca en el extranjero. • También estaba presente en el modelo de vehículo anterior (Opel Astra G). • Sólo dispone de dos líneas para mostrar información.
BID – Board Info Display (Ilustración 42) | • Este fue el primer modelo en llegar a España. Se suministraba con los vehículos vendidos en los primeros años (alrededor de 2004) • Incluye de tres líneas de información, lo que le permite mostrar información acerca del sistema de infoentretenimiento.
GID – Graphical Info Display (Ilustración 43) | • Este modelo también se suministraba desde los primeros años en España, aunque se incluía en el modelo deportivo (GTC) y gamas medias / altas. • Distribuye la información en pantalla de forma mucho más clara.
CID – Colour Info Display (Ilustración 44) | • Soporte para mostrar contenido a color. • Disponible a partir del año 2008. • Al basarse en una pantalla LCD tiene mucho más potencial que los anteriores modelos. • Aunque no de forma oficial, soporta entradas de vídeo analógicas de cámaras traseras y/o laterales.

TABLA 23 – OPEL ASTRA H – TIPOS DE PANTALLA

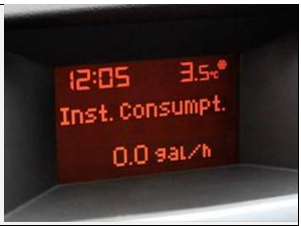
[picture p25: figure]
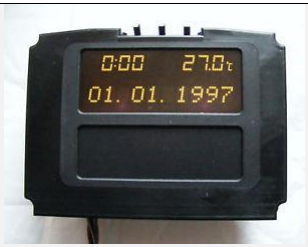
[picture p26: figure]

ILUSTRACIÓN 41 – MODELO DE PANTALLA TID | ILUSTRACIÓN 42 – MODELO DE PANTALLA BID

ILUSTRACIÓN 43 – MODELO DE PANTALLA GID | ILUSTRACIÓN 44 – MODELO DE PANTALLA CID

5.2.4.1.1 – ENVÍO DE TEXTO A LA PANTALLA

El método empleado para enviar textos a la pantalla es un poco complejo debido entre otras cosas, a la longitud variable de los textos y al tamaño máximo de mensaje CAN.

Por ello la pantalla emplea el estándar ISO 15765-2, el cual divide los datos en mensajes de menor tamaño con un identificador de secuencia para poder re-ensamblarlo en el otro extremo. A grandes rasgos realiza una función similar al protocolo TCP en la pila de protocolos TCP/IP.

Antes de comenzar a enviar texto es necesario realizar una solicitud a la pantalla para proceder con el envío. Esto se realiza mediante un mensaje al que se le denomina DIS_TEXT_REQUEST, el cual está descrito en la tabla 24.

El mensaje tiene los siguientes campos:
- Comando – Indica el comando para enviar un texto. Sólo se utiliza el 0xC000.
- Textos – En plural. Es posible con una única solicitud enviar varios textos a varias posiciones distintas.
- Tipo de texto – La categoría a la que corresponde el texto:
- 0x01 – Sección de radio FM.
- 0x03 – Sección de pantalla principal. (La única compatible con la pantalla BID).
- 0x05 – Sección de origen CD.
- 0x07 – Sección de teléfono móvil.
- 0x09 – Sección de navegador GPS.
- 0x0A – Sección del climatizador / aire acondicionado.
- Posición – A qué se corresponde el texto y donde debe mostrarse:
- 0x01 – Nombre de la emisora de radio.
- 0x10 – Nombre de la canción.
- 0x24 – Temperatura del climatizador.

Mensaje DIS_TEXT_REQUEST
ID | data[0] | data[1] | data[2] | data[3] | data[4] | data[5] | data[6] | data[7]
0x6C1 | 0x10 (Solicitud) | Longitud mensajes (bytes) | Comando (Siempre 0xC000) | | Longitud Textos (bytes) | Tipo de texto | ID Posición | Longitud Posición

TABLA 24 – OPEL ASTRA H – FORMATO DEL MENSAJE DIS_TEXT_REQUEST

Tras el envío de este mensaje, instantáneamente recibiremos una confirmación para poder realizar el envío del texto. A esta confirmación se le denomina DIS_REQUEST_ACK, el cual está descrito en la tabla 25.

Mensaje DIS_REQUEST_ACK
ID | data[0] | data[1] | data[2] | data[3] | data[4] | data[5] | data[6] | data[7]
0x2C1 | 0x30 ACK - OK | 0x00 | 0x00 | 0x00 | 0x00 | 0x00 | 0x00 | 0x00

TABLA 25 – OPEL ASTRA H – FORMATO DEL MENSAJE DIS_REQUEST_ACK

Tras todas las investigaciones desconozco si hay alguna respuesta NACK, ya que nunca he recibido ningún valor distinto de 0x30 ni hay información pública al respecto. En cualquier caso, el desarrollo contempla esta posible situación y se reintenta el envío del texto pasados unos segundos en caso de recibir un valor distinto.

Por último, se procede al envío del texto en formato Unicode-16. Esto quiere decir que por cada carácter a enviar se van emplear 2 Bytes. Además, no hay que olvidar que al emplear el estándar ISO 15765-2 sólo tenemos 7 bytes de datos con cada envío, lo que quiere decir que realmente con cada mensaje se enviarán 3 caracteres y medio.

La tabla 26 muestra un ejemplo del envío del texto “1234567890” empleando los mensajes denominados DIS_SEND_TEXT.

Secuencia de mensajes DIS_SEND_TEXT
ID | data[0] | data[1] | data[2] | data[3] | data[4] | data[5] | data[6] | data[7]
0x6C1 | «Secuencia» 0x21 | 0x00 | 0x31 | 0x00 | 0x32 | 0x00 | 0x33 | 0x00
| | ‘1’ | | ‘2’ | | ‘3’ | | ½ ‘4’
0x6C1 | «Secuencia» 0x22 | 0x34 | 0x00 | 0x35 | 0x00 | 0x36 | 0x00 | 0x37
| | ½ ‘4’ | ‘5’ | | ‘6’ | | ‘7’
0x6C1 | «Secuencia» 0x23 | 0x00 | 0x38 | 0x00 | 0x39 | 0x00 | 0x30 | -
| | ‘8’ | | ‘9’ | | ‘0’

TABLA 26 – OPEL ASTRA H – FORMATO DE LA SECUENCIA DE MENSAJES DIS_SEND_TEXT

Hay un inconveniente a la hora de enviar textos de mayor longitud que la admitida en línea principal de la pantalla. Al no caber entero, el texto simplemente se corta al ser recibido y se ignora la parte sobrante.

Esto está solventado en el software implementado en la controladora genérica que recoge este documento simulando el efecto de una marquesina en movimiento. De esta forma el texto va desplazándose poco a poco y se visualiza por completo.

5.2.4.1.2 – DIAGNÓSTICO DEL VEHÍCULO – “MODO TEST” O “MENÚ SECRETO”

El “Modo Test” es el nombre que recibe el menú oculto del Opel Astra H que permite visualizar información del vehículo en tiempo real.

Recibe este nombre ya que al activarse muestra el texto “Test Mode” por la pantalla, pero realmente lo único que hace es mostrar un menú oculto en las opciones de la pantalla. Está implementado en el hardware y en el software de la pantalla.

Toda la información que muestra está accesible por el bus de datos, por lo que realmente no se altera ningún parámetro interno del vehículo o se llega más allá que a la simple visualización de algunos valores internos.

Es posible habilitar este modo con la radio original manteniendo pulsado el botón «Settings» hasta que se escuche un pitido por los altavoces (alrededor de 8 o 10 segundos) y posteriormente pulsar el botón «BC». El problema reside en que si quitamos la radio original perdemos el acceso a estos botones y no es posible realizar la secuencia. La controladora genérica permite acceder de nuevo a este menú mediante la emulación del equipo de sonido original.

Este modo tiene una apariencia como la que podemos observar en las ilustraciones 45 y 46.

- U-Term30: El voltaje de la batería (terminal 30)
- LED/LCD Tmp: Temperatura de la pantalla.
- Chart y LEDs: Brillo de la pantalla y de los instrumentos.

ILUSTRACIÓN 45– “MODO TEST” O “MENÚ SECRETO” (1)

- Speed: La velocidad actual del automóvil.
- Coolant: La temperatura del líquido refrigerante.
- Sensor: La temperatura del aire en la entrada al motor.
- Ice-Active: Si se muestra o no el aviso por posibles placas de hielo en el asfalto.

ILUSTRACIÓN 46 – “MODO TEST” O “MENÚ SECRETO” (2)

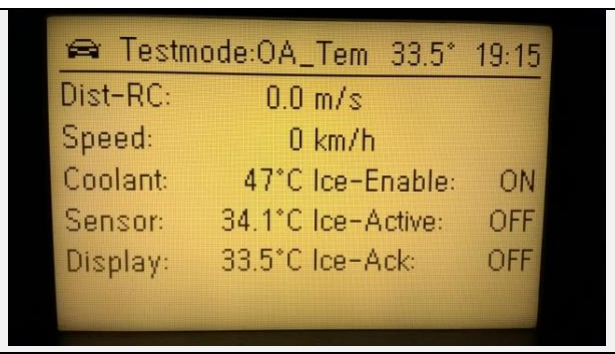
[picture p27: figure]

5.2.4.2 – EHU – ENTERTAINMENT UNIT

La “EHU” es el nombre interno que recibe el sistema de sonido original del vehículo.

En la ilustración 47 podemos ver una imagen del equipo de sonido CD30 MP3.

Existen múltiples sistemas de sonido originales al igual que las pantallas, pues varían dependiendo de la gama del vehículo y de la
fecha de compra.

En este caso carece de sentido entrar en detalle
en los distintos modelos, pues simplemente aumentan sus funcionalidades internas, pero no son pertinentes para el desarrollo de este proyecto.

Este componente está íntimamente ligado con la pantalla, pues incluye ciertos botones referentes a la misma. En la ilustración 47 podemos visualizar los botones «Settings» y «BC»

ILUSTRACIÓN 47 – SISTEMA DE SONIDO CD30 MP3 comentados anteriormente además de una cruceta de dirección que se utiliza para navegar y modificar algunos parámetros del vehículo como por ejemplo la fecha y la hora.

En circunstancias normales, si este componente es reemplazado por uno no oficial se vuelven inaccesibles todas las funcionalidades a las que se accede con esos botones. Pero gracias a este proyecto es posible simular los botones perdidos y no perder el acceso a unas configuraciones tan básicas como la fecha y la hora o el idioma del sistema.

Es importante tener en cuenta que, si reemplazamos este componente por otro no original, el nuevo no se conectará al bus de datos y el vehículo no será consciente de este cambio. Esto provoca el registro de un error interno debido a la falta del equipo, lo cual no resulta problemático, pero puede causar confusión en caso de averías.

Para subsanarlo disponemos de dos opciones:
- Desde la herramienta de configuración y diagnóstico oficial para talleres autorizados (OPCOM) es posible indicar que el equipo de infoentretenimiento está desconectado. Esto provoca que el “Modo Test” deje de estar disponible incluso aunque se envíe por el CAN BUS los mensajes para habilitarlo.
- La controladora genérica incluye un modo de simulación de EHU para que este error no se registre y se siga manteniendo el acceso a todas las funcionalidades.

5.2.4.3 – CIM – COLUMN INTEGRATED MODULE / STEERING COLUMN MODULE

Este componente recibe el nombre de
“Column Integrated Module” en los vehículos
fabricados hasta el año 2006, pero en adelante
se denomina “Steering Column Module”. Se
encuentra situado en el volante del automóvil.

También se encarga de tomar las pulsaciones

de los botones situados en el volante (ver ilustración 48) y convertirlas en mensajes que se envían por el bus CAN.

Se podría decir que es el coordinador central del bus de datos de media velocidad, pues también está conectado al resto de buses de datos del automóvil y retransmite información importante entre los distintos buses de datos. Como por ejemplo el voltaje de la batería y la temperatura del líquido refrigerante.

Entre sus funciones podemos encontrar la comunicación del estado del contacto por el bus de datos. Es decir, es el encargado de notificar al resto de sistemas de que el vehículo tiene la llave correcta introducida y va a ser arrancado o incluso que ya está encendido.

Esos mensajes siguen el formato descrito a continuación en la tabla 27.
Mensaje de pulsación o liberación de botones en el volante
ID | data[0] | data[1] | data[2]
0x206 | • 0x01 – Pulsación • 0x00 – Liberación | «Número de secuencia empezando en 0x01, sólo para pulsación» | • 0x84 – Botón rueda izquierda. • 0x91 – Botón superior derecho. • 0x92 – Botón inferior derecho. • 0x81 – Botón superior izquierdo. • 0x82 – Botón inferior izquierdo.

TABLA 27 – OPEL ASTRA H – FORMATO DEL MENSAJE DE LA PULSACIÓN O LIBERACIÓN DE LOS BOTONES DEL VOLANTE

ILUSTRACIÓN 48 – VOLANTE VAUXHALL H

Si la pulsación se mantiene, cada 100ms se enviará un nuevo mensaje incrementando el contador de secuencia. La tabla 28 muestra un ejemplo de pulsar y mantener el botón superior derecho durante 350ms.

ID | data[0] | data[1] | data[2] | Momento de envío
0x206 | 0x01 – Pulsación | 0x01 | 0x91 | 0ms
0x206 | 0x01 – Pulsación | 0x02 | 0x91 | 100ms
0x206 | 0x01 – Pulsación | 0x03 | 0x91 | 200ms
0x206 | 0x01 – Pulsación | 0x04 | 0x91 | 300ms
0x206 | 0x00 – Liberación | 0x00 | 0x91 | 350ms

TABLA 28 – OPEL ASTRA H – EJEMPLO DE MENSAJES AL MANTENER UN BOTÓN DURANTE 350MS.

Además de botones, el volante cuenta con un par de ruedas a cada lado que también generan comandos en el bus de datos de forma muy similar a la ya vista. Se puede ver en detalle en la tabla 29.

Mensaje al mover las ruedas situadas en el volante
ID | data[0] | data[1] | data[2]
0x206 | 0x08 Movimiento de rueda | • 0x93 – Rueda derecha • 0x83 – Rueda izquierda. | • 0x01 – Arriba • 0xFF – Abajo

TABLA 29 – OPEL ASTRA H – FORMATO DEL MENSAJE AL MOVER LAS RUEDAS DEL VOLANTE

### 5.2.5 – ACCIONES IMPLEMENTADAS

La especificación de vehículos normalmente añade nuevas acciones. A continuación, en las tablas 30 a 33 se detallan los comandos del Opel Astra H.

Vehículo – Prefijo OPT
Función | Parámetros | Descripción
get | 1. Nombre del módulo | Obtiene o establece si se debe activar un módulo específico. Módulos válidos: • SIM – Simulación de radio • LED – Uso de LEDs adicionales. • CAR – Monitor de estado del vehículo. • TST – Modo “Test” • DIS – Módulo de la pantalla.
set | 1. Nombre del módulo 2. Valor

TABLA 30 – ACCIONES – FUNCIONES ESPECÍFICAS DEL VEHÍCULO – OPT

Vehículo – Prefijo LOG
Función | Parámetros | Descripción
get | 1. Nombre del módulo | Obtiene o establece si se debe mostrar un registro específico. Registros válidos: • DIS – Pantalla principal
set | 1. Nombre del módulo 2. Valor

TABLA 31 – ACCIONES – FUNCIONES ESPECÍFICAS DEL VEHÍCULO – LOG

Vehículo – Prefijo BC
Función | Parámetros | Descripción
settings | - | Simula la pulsación del botón “Settings”.
bc | - | Simula la pulsación del botón “BC”.
up | - | Simula la pulsación de un botón de la cruceta de dirección.
down | -
left | -
right | -

TABLA 32 – ACCIONES – FUNCIONES ESPECÍFICAS DEL VEHÍCULO – BC

Vehículo – Prefijo DIS
Función | Parámetros | Descripción
set | 1. Texto a mostrar | Establece el texto a mostrar por la pantalla principal.

TABLA 33 – ACCIONES – FUNCIONES ESPECÍFICAS DEL VEHÍCULO – DIS

## 7 – PRESUPUESTO

En este punto se van a recoger tanto los elementos necesarios como recomendables para poder ensamblar el proyecto.

### 7.1 – HERRAMIENTAS

A continuación, en la tabla 34 se citan las herramientas empleadas para el montaje del proyecto.

Nombre | Precio medio (€) | Descripción
Polímetro digital | 30,00 € | Un polímetro digital para realizar mediciones y comprobar la continuidad entre distintos puntos del circuito.
Osciloscopio USB | 70,00 € | Necesario para analizar señales. Al ser USB es muy cómodo de llevar al coche junto al ordenador portátil.
Pelacables | 15,00 € | Recomendable, especialmente para pelar muchos cables rápidamente y sin quitar ninguna vena del interior.
Soldador (punta 1mm) | 45,00 € | Recomendable el JBC 14ST de 11W o equivalente.
Impresora 3D | 250,00 € | Se puede encargar la impresión del mecanizado a un proveedor y ahorrarse la compra.
Pistola de silicona caliente | 10,00 € | Se puede reemplazar por algún otro tipo de adhesivo.
Pistola de aire caliente | 17,00 € | Se utiliza para contraer los tubos termo-retractiles. Es posible reemplazarlo por un mechero o el propio soldador, pero no es recomendable.
Limas metálicas de relojería | 10,00 € | Recomendable para finalizar los acabados del mecanizado.

TABLA 34 – PRESUPUESTO – HERRAMIENTAS

### 7.2 – COMPONENTES

La tabla 35 contiene todos los componentes y piezas necesarias para ensamblar la controladora genérica al completo, con todos los módulos opcionales y su mecanizado.

Nombre | Precio unitario (€) | Cantidad | Subtotal
Placa base (Desde proveedor JLC PCB) | 0,90 € | 1 | 0,90 €
Arduino Nano v3 | 4,00 € | 1 | 4,00 €
Módulo CAN MCP2515 | 4,30 € | 1 | 4,30 €
Módulo GPS NEO-6MV2 | 15,00 € | 1 | 15,00 €
Módulo GSM SIM800L | 15,00 € | 1 | 15,00 €
Módulo Bluetooth HC-05 / HC-06 | 8,00 € | 1 | 8,00 €
Potenciómetro digital MCP4131 | 1,00 € | 1 | 1,00 €
Fuente de alimentación conmutada 5A | 2,80 € | 2 | 5,40 €
Optoacoplador PC817 | 0,10 € | 1 | 0,10 €
Mecanizado (Controladora + Fte. alimentación) | 45,00 € | 1 | 45,00 €

TABLA 35 – PRESUPUESTO – COMPONENTES

### 7.3 – CONSUMIBLES

La tabla 36 muestra los consumibles necesarios para ensamblar el circuito. Se asume como consumible los elementos de pequeño valor que simplemente se emplean para interconectar o ensamblar el resto de componentes.

Nombre | Precio unitario (€) | Cantidad | Subtotal
Resistencia (220Ω) | 0,10 € | 3 | 0,30 €
Resistencia (1000Ω) | 0,10 € | 1 | 0,10 €
Resistencia (2200Ω) | 0,10 € | 1 | 0,10 €
Diodo 1N914 | 0,10 € | 1 | 0,10 €
Conmutador SPDT de 3 pines | 0,05 € | 2 | 0,10 €
Conector Jack 3.5mm hembra | 0,65 € | 1 | 0,65 €
Conectores de 3 pines macho y hembra (pack) | 0,05 € | 6 | 0,30 €
Conectores Dupont 2.54mm hembra (40 pines) | 0,15 € | 4 | 0,60 €
Tornillo M4 | 0,02 € | 4 | 0,08 €
Espaciador / tuerca M4 | 0,02 € | 4 | 0,08 €
Regleta de conexiones eléctricas AWG 22 | 1,15 € | 1 | 1,15 €
Cable AWG 22 (preferible cobre) (metro) | 2,00 € | 5 | 10,00 €
Estaño 99% puro. 1mm de grosor (rollo) | 12,00 € | 1 | 12,00 €
Plástico para impresora 3D (1KG) | 18,00 € | 1 | 18,00 €
Tubos de adhesivo termofusible (silicona) | 0,10 € | 2 | 0,20 €
Bridas de sujeción | 0,05 € | 10 | 0,50 €
Tubo termo-retráctil | 0,02 € | 20 | 0,40 €

TABLA 36 – PRESUPUESTO – CONSUMIBLES

### 7.4 – DESARROLLO

En la tabla 37 se especifican la cantidad de horas empleadas para llevar a cabo el desarrollo completo y la documentación de este proyecto.

Nombre | Precio hora (€) | Cantidad | Subtotal
Hora de desarrollador | 12,00 € | 300 | 3.600,00 €
Hora de tutor | 24,00 € | 30 | 720,00 €

TABLA 37 – PRESUPUESTO – DESARROLLO

### 7.5 – COSTES PERIÓDICOS

En este punto se detallan los costes mensuales que se deben asumir para tener en funcionamiento la plataforma de seguimiento, los cuales están visibles en la tabla 38.

Nombre | Precio mes (€)
Plataforma Traccar (sin servidor dedicado) (1 cuenta) | 10,00 €
Tarifa de datos GSM | 6,00 €

TABLA 38 – PRESUPUESTO – COSTES PERIÓDICOS

## 7.6 – TOTAL

A continuación, en la tabla 39, se detalla el total del sumatorio de todas las partes del presupuesto acorde a si se adquiere una impresora 3D o no.

Apartado del presupuesto | Comprando Impresora 3D | Precio total del apartado (€)
Herramientas | Sí | 447,00 €
| No | 187,00 €
Componentes y piezas | Sí | 51,10 €
| No | 96,10 €
Consumibles | Sí | 35,69 €
| No | 17,69 €
Desarrollo | - | 4320,00 €
Costes mensuales (1 año) | - | 192,00 €
TOTAL | Sí | 5.045,69 €
| No | 4.812,69 €
PRECIO POR UNIDAD (Producción en masa) | - 40,00 €

TABLA 39 – PRESUPUESTO – TOTAL
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

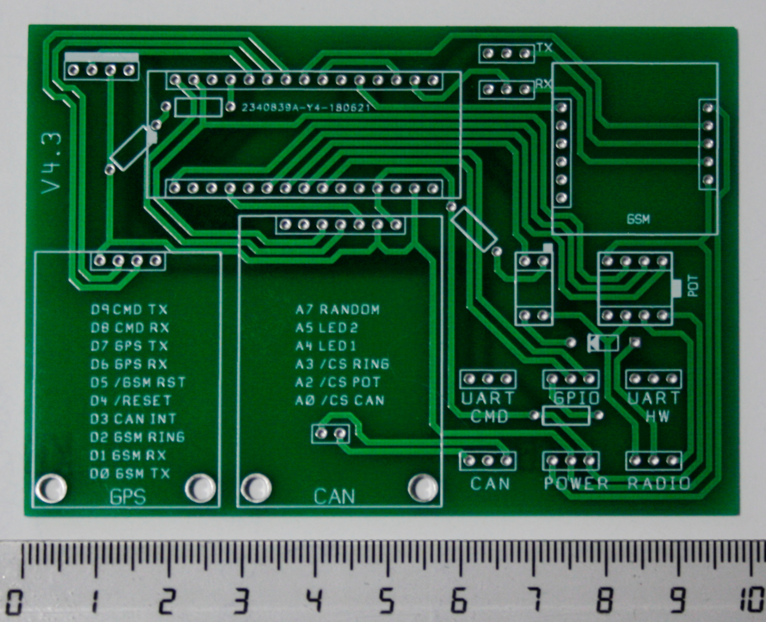
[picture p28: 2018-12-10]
img/v43_front.JPG

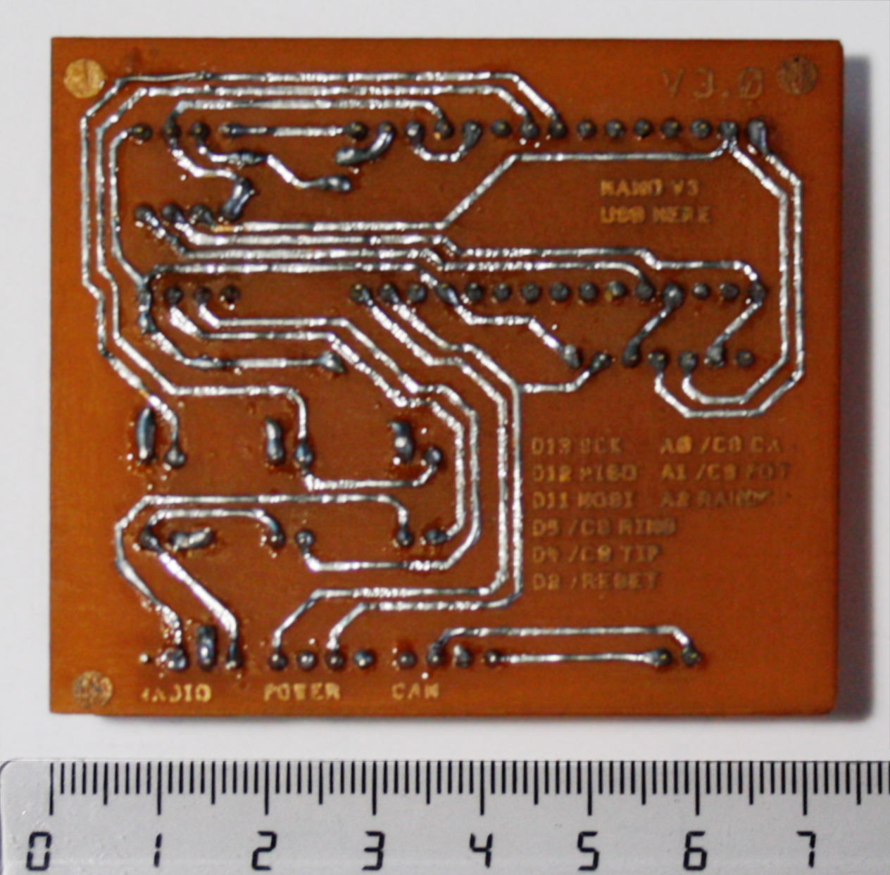
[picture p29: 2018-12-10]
img/v3_back.JPG

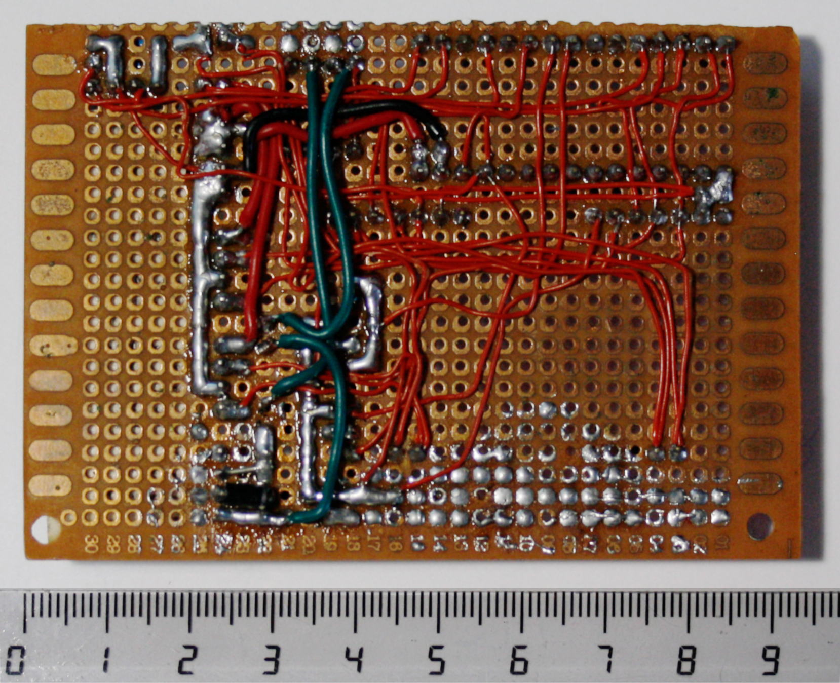
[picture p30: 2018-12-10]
img/v2_back.JPG

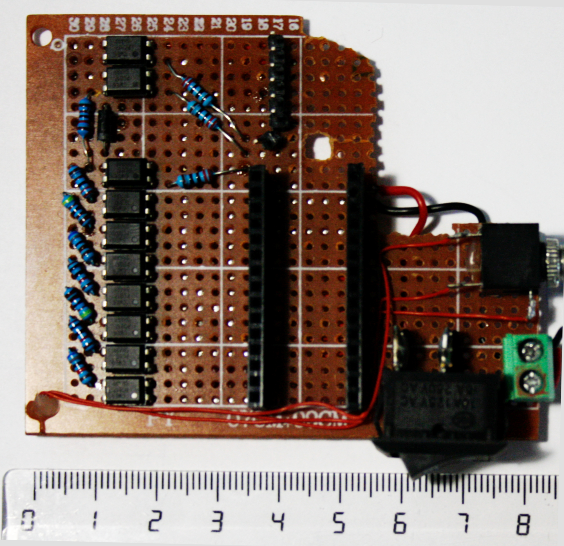
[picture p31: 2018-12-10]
img/v1_front.JPG

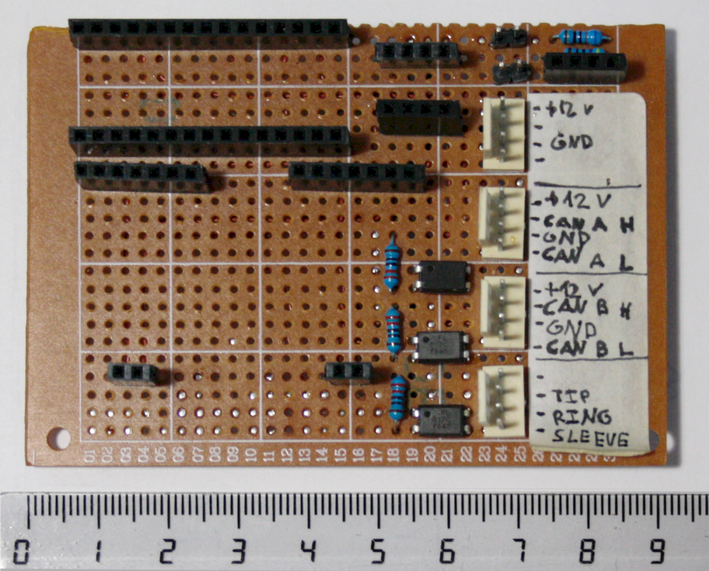
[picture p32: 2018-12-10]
img/v2_front.JPG

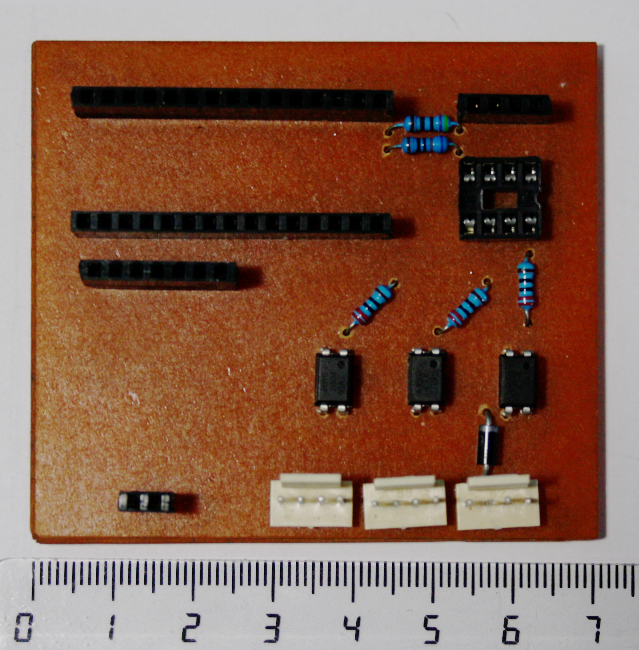
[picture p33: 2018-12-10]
img/v3_front.JPG

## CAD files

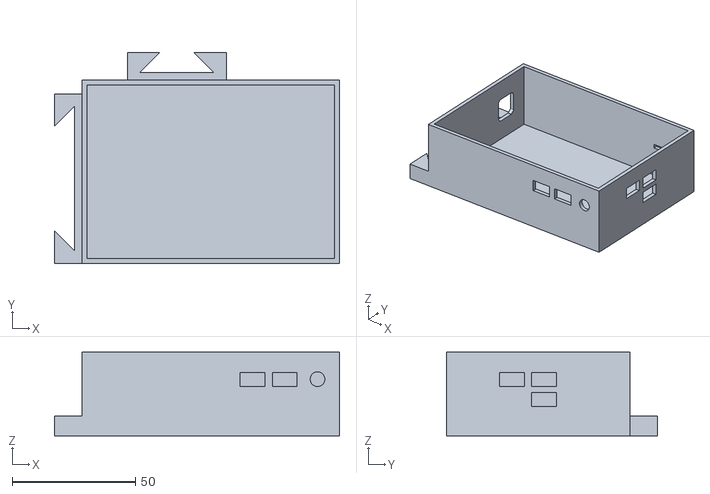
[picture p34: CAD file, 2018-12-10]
Case/Case V4.3.stl
115.4 x 85.4 x 34.0

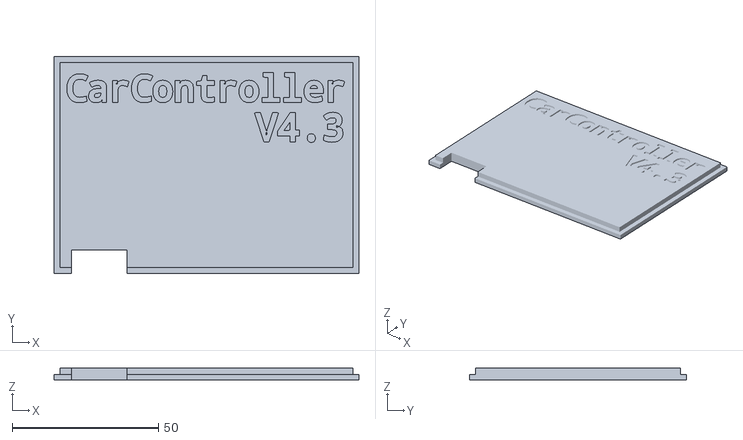
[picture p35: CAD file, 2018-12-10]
Case/Cover V4.3.stl
104.2 x 74.2 x 4.25

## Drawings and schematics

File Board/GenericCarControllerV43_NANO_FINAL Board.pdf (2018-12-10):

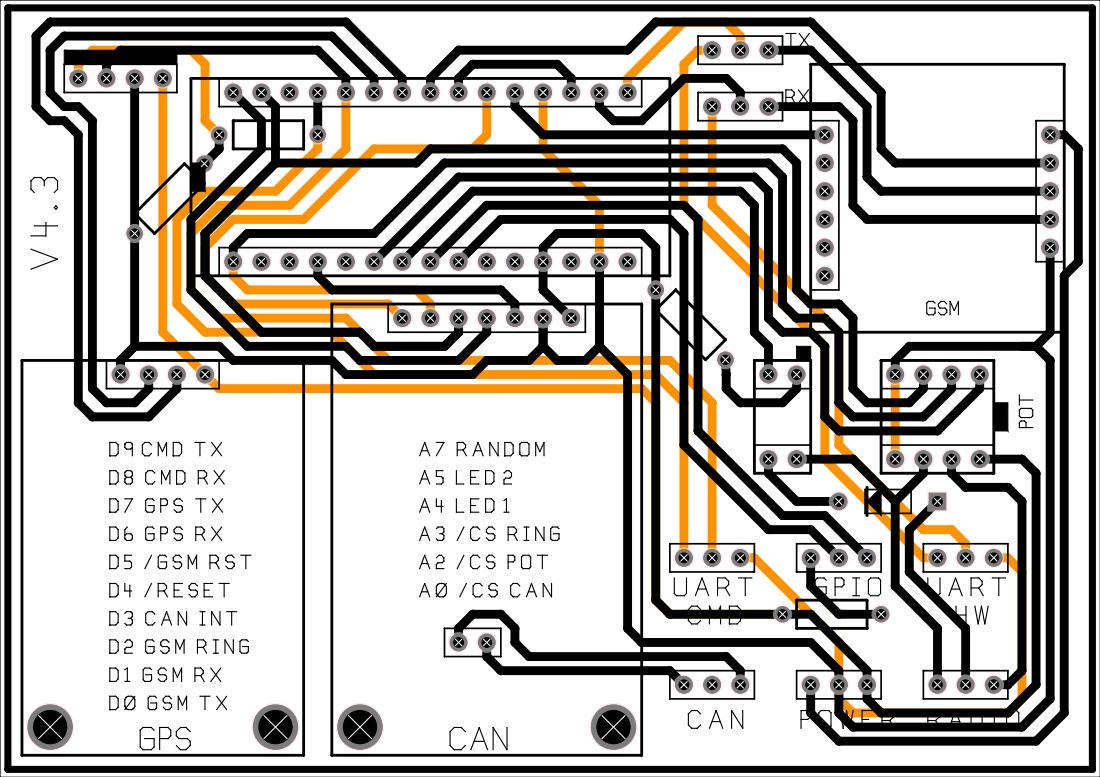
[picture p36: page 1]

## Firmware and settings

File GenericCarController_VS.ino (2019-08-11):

//
// Author:	Álvaro Graciá Gil
// License:	This work is licensed under a Creative Commons Attribution-NonCommercial-ShareAlike 4.0 International License 
//	 		(http://creativecommons.org/licenses/by-nc-sa/4.0/) 
//

#include <SPI.h>
#include "configuration.h"
#include "configuration_eeprom.h"
#include "potentiometer.h"
#include "radio_command.h"
#include "can_command.h"
#include "can_controller.h"
#include "utils.h"
#include "power.h"
#include "gsm.h"
#include "gps.h"
#include "traccar.h"
#include "cmd_serial.h"
#include "serial_controller.h"
#include "base_serial_handlers.h"
#include "injection.h"
#include "car_status.h"

void setup();
void loop();
void carAfterLoop();
void carBeforeSetup();
void carAfterSetup();

CONFIGURATION CONFIG;

#if COMPILE_CAN
	void carAfterCmdReceived(CAN_CONTROLLER *can, CAN_COMMAND *receivedCmd);
	CAN_CONTROLLER DEFAULT_CAN	= CAN_CONTROLLER(CAN_A_CS_PIN, CAN_A_INT_PIN, carAfterCmdReceived);
#endif

void setup()
{	
	setupPOW();
	setupCMDSerial();

	#if COMPILE_EEPROM_CONFIG	
		if (!eepromLoad(&CONFIG))
		{
			CONFIG.setDefaults();
			eepromSave(&CONFIG);
		}
	#endif

	carBeforeSetup(); //CAR SETUP
     
	#if COMPILE_POTENTIOMETER
		if (CONFIG.get(PRINT_STATUS_INFO))
		{			
			cmdSerialPrint_P(sPOT);
			cmdSerialPrint_P(sSpace);

			if (setupPOT()) cmdSerialPrintln_P(sOK);
			else cmdSerialPrintln_P(sERROR);
		}
		else setupPOT();
	#endif

	#if COMPILE_GPS
		if (CONFIG.get(PRINT_STATUS_INFO))
		{			
			utilsPrint_P(sGPS);
			utilsPrint_P(sSpace);

			if (setupGPS()) utilsPrintln_P(sOK);
			else utilsPrintln_P(sERROR);
		}
		else setupGPS();
	#endif  
  
	#if COMPILE_GSM_MODEM
		if (CONFIG.get(PRINT_STATUS_INFO))
		{
			utilsPrint_P(sGSM);
			utilsPrint_P(sSpace);

			if (setupGSM()) utilsPrintln_P(sOK);
			else utilsPrintln_P(sERROR);
		}
		else setupGSM();
	#endif
  
	#if COMPILE_TRACCAR
		if (CONFIG.get(PRINT_STATUS_INFO))
		{
			utilsPrint_P(sTRC);
			utilsPrint_P(sSpace);

			if (setupTraccar()) utilsPrintln_P(sOK);
			else utilsPrintln_P(sERROR);
		}
		else setupTraccar();
	#endif
  
	#if COMPILE_CAN   
		DEFAULT_CAN.setupPins();
		if (CONFIG.get(PRINT_STATUS_INFO))
		{
			cmdSerialPrint_P(sCAN);
			cmdSerialPrint_P(sSpace);
		}
		
		if (!DEFAULT_CAN.begin(CAN_BAUDRATE, CAN_CLOCKSET))
		{
			if (CONFIG.get(PRINT_STATUS_INFO))
			{
				cmdSerialPrint_P(sERROR);
				cmdSerialFlush();
			}

			utilsResetSystem();
		}
		else if (CONFIG.get(PRINT_STATUS_INFO))
			cmdSerialPrintln_P(sOK);
	#endif
      
	#if COMPILE_SERIAL_CONTROL    
		#if SERIAL_CONTROL_MODE >= SC_MIN
			SerialController.addHandler(new SERIAL_HANDLER(sSYS, SYSHandleConfCmd));
       
			#if COMPILE_EEPROM_CONFIG
				SerialController.addHandler(new SERIAL_HANDLER(sLOG, LOGHandleConfCmd));
				SerialController.addHandler(new SERIAL_HANDLER(sOPT, OPTHandleConfCmd));
				SerialController.addHandler(new SERIAL_HANDLER(sROM, ROMHandleConfCmd));
			#endif
		#endif

		#if SERIAL_CONTROL_MODE >= SC_MID
			#if COMPILE_CAN
				SerialController.addHandler(new SERIAL_HANDLER(sCAN, CANHandleConfCmd));
			#endif
		#endif
	#endif
	
	#if ENABLE_INJECTION
		setupInjection();
	#endif

	carAfterSetup(); //CAR SETUP 
}

#if COMPILE_DEBUG
	static unsigned long prev = 0;
	void prePrint()
	{
		prev = micros();
	}

	void postPrint(const PROGMEM char *type)
	{
		cmdSerial.print(micros() - prev);
		utilsPrint_P(sSpaceCommaSpace);
		utilsPrintln_P(type);
	}
#endif

void loop()
{
	#if COMPILE_DEBUG
		if (CONFIG.get(PRINT_DEBUG))
		{
			prePrint();
			checkPOW();
			postPrint(sPOW);

			#if COMPILE_CAN
				prePrint();
				DEFAULT_CAN.checkCAN();
				postPrint(sCAN);
			#endif

			#if COMPILE_TRACCAR
				prePrint();
				checkTraccar();
				postPrint(sTRC);
			#endif

			#if COMPILE_GSM_MODEM
				prePrint();
				checkGSM();   
				postPrint(sGSM);
			#endif

			#if COMPILE_POTENTIOMETER
				prePrint();
				checkPOT();
				postPrint(sPOT);
			#endif
  
			#if COMPILE_CAR_STATUS_MONITOR
				prePrint();
				checkCarStatus();
				postPrint(sSTA);
			#endif

			#if COMPILE_SERIAL_CONTROL
				prePrint();
				checkCMDSerial();	
				postPrint(PSTR("CMD"));
			#endif

			#if ENABLE_INJECTION
				prePrint();
				checkInjection();		
				postPrint(PSTR("INJ"));
			#endif

			prePrint();
			carAfterLoop();
			postPrint(sCAR);
		}
		else
	#endif
	{
		checkPOW();

		#if COMPILE_CAN			
			DEFAULT_CAN.checkCAN();			
		#endif

		#if COMPILE_TRACCAR		
			checkTraccar();			
		#endif

		#if COMPILE_GSM_MODEM			
			checkGSM();   			
		#endif

		#if COMPILE_POTENTIOMETER			
			checkPOT();			
		#endif
  
		#if COMPILE_CAR_STATUS_MONITOR			
			checkCarStatus();			
		#endif

		#if COMPILE_SERIAL_CONTROL			
			#ifdef CMD_SERIAL_MODE
				checkCMDSerial();				
			#endif	
		#endif

		#if ENABLE_INJECTION			
			checkInjection();					
		#endif
  		
		carAfterLoop();
	}
}

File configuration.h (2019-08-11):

//
// Author:	Álvaro Graciá Gil
// License:	This work is licensed under a Creative Commons Attribution-NonCommercial-ShareAlike 4.0 International License 
//	 		(http://creativecommons.org/licenses/by-nc-sa/4.0/) 
//

#ifndef __CONFIGURATION_H__
	#define __CONFIGURATION_H__
	
	#include "customArduino.h"
	#include "constants.h"
	#include "configuration_secret.h"
	
	/********* CARS **********/
	#define NONE_CAR					0
	#define OPEL_ASTRA_H_2004_CAR		1
	#define FORD_FOCUS_2004_CAR			2
	#define TOYOTA_COROLLA_2000_CAR		3
	#define OPEL_ASTRA_H_2004_MIN_CAR	4

	/********* CONFIG **********/
	#define CAR_MODEL								OPEL_ASTRA_H_2004_CAR
	#define BOARD_VERSION							43

	#define COMPILE_DEBUG							0
	#define COMPILE_CAN								1
	#define COMPILE_CAN_PIN_CMD_AVAILABLE			1
	#define COMPILE_CAN_INTERRUPT					1
	#define COMPILE_CAN_WHITELIST					1
	#define COMPILE_CAN_BLACKLIST					0
	#define COMPILE_CAN_PERIODICAL					1
	#define COMPILE_RADIO_CONTROL					1
	#define COMPILE_POTENTIOMETER					1
	#define COMPILE_SERIAL_CONTROL					1
	#define COMPILE_EEPROM_CONFIG					1
	#define COMPILE_TRACCAR							0
	#define COMPILE_GPS								0
	#define COMPILE_GSM_MODEM						0
	#define COMPILE_CAR_STATUS_MONITOR				0	//It occupies around 1KB of code and consumes 40 bytes of RAM	

	//INJECTION	
	#define ENABLE_INJECTION						0
	#define INJECT_SEQUENTIAL_COMMANDS				0

	//RADIO
	#define RADIO_COMMAND_MIN_INTERVAL				50	//ms
	#define RADIO_COMMAND_MAX_INTERVAL				110 //ms
	#define RADIO_USE_TIP_OPTOCOUPLERS				0	

	//POT
	#define POT_SHOW_KOHMS							0		

	//CAN
	#define CAN_CLOCKSET							MCP_8MHZ	
	#define CAN_MODE_LOOPBACK						0
	#define CAN_RX_QUEUE_LENGTH						10		//items
	#define CAN_TX_QUEUE_LENGTH						14		//items
	#define CAN_INIT_MAX_RETRIES					5
	#define CAN_MIN_COMMAND_INTERVAL				10		//ms
	#define CAN_DISABLE_INTERRUPTS_AT_TRANSFER		0
	#define CAN_ENABLE_MIN_DELAY_BETWEEN_COMMANDS	1
	#define CAN_ENABLE_TX_QUEUE						1
	#define CAN_TX_RETRY_TIMEOUT					10		//ms
	#define CAN_HANDLE_ERRORS_ON_ONTERRUPT			0
	#define CAN_INTERRUPT_MODE_FLAG					1
	#define CAN_INTERRUPT_MODE_FETCH				2
	#define CAN_INTERRUPT_MODE						CAN_INTERRUPT_MODE_FETCH
	#define CAN_DEBUG_PRINT_QUEUE_STATS				1

	//SERIAL
	#define DEBUG_INVERT_SERIAL				1
	#define DEFAULT_BAUDRATE                57600	//115200 fails (NeoIC)		
	#define SC_FULL                         3		//GSM + GPS + POT CALIBRATION + POT SET + [MID]
	#define SC_MID                          2		//RAD + BC + CAN + [MIN]
	#define SC_MIN                          1		//SYS + POW + LOG + OPT +  DIS
	#define SERIAL_CONTROL_MODE             SC_FULL
	#define CMD_SERIAL_BUFFER_SIZE			64
	#define CMD_USE_SERIAL_INTERRUPTS		1
	#define MAX_SERIAL_HANDLERS				14
	#define MAX_PARAMETERS					9
	#define HW_SERIAL						1
	#define IC_SERIAL						2
	#define SW_SERIAL						3	

	//GPS
	#define GPS_BAUDRATE					9600
	#define GPS_SERIAL_ALWAYS_ENABLED		0

	//GSM
	#define GSM_BAUDRATE							9600 //115200 fails (NeoHW)	
	#define GSM_GET_MAX_TIMEOUT						25 * 1000L	//ms
	#define GSM_GET_MAX_ERRORS_BEFORE_RESET			3
	#define GSM_SETUP_MAX_TIMEOUT					60 * 1000L	//ms -> Prev = 30s //TODO -> CHECK	
	#define GSM_SETUP_RESET_LOW_DELAY				100 //ms
	#define GSM_DISABLE_LEDS						1
	#define GSM_SERIAL_BUFFER_SIZE					32
	#define GSM_USE_SERIAL_INTERRUPTS				1
	#define GSM_USE_FLASH_STRINGS					1	//if disabled, consumes 198 bytes of RAM	
	#define GSM_COMMAND_QUEUE_LENGTH				3		

	#if GSM_USE_FLASH_STRINGS
		#define GSM_STR(A) PSTR(A)
	#else
		#define GSM_STR(A) A
	#endif

	//MEM
	#define USE_STATIC_MEM					1

	//POWER
	#define POW_ENABLE_WATCHDOG				0
	#define POW_WATCHDOG_TIMEOUT			WDTO_60MS

	//CAR STATUS MONITOR
	#define MON_FETCH_VOLTAGE				0
	#define MON_CHECK_VOLTAGE				0
	#define MON_MIN_VOLTAGE					12
	#define MON_MAX_VOLTAGE					15
	#define MON_REPORT_VOLTAGE				1	
	#define MON_REPORT_VOLTAGE_LENGTH		6 //VX.YZ<space>
	#define MON_REPORT_VOLTAGE_TRACCAR		1	

	#define MON_FETCH_ENGINE_TEMP			1
	#define MON_CHECK_ENGINE_TEMP			1
	#define MON_MAX_ENGINE_TEMP				105
	#define MON_REPORT_ENGINE_TEMP			1
	#define MON_REPORT_ENGINE_TEMP_LENGTH	5 //VXYZ<space>	
	#define MON_REPORT_ENGINE_TEMP_TRACCAR	1	

	#define MON_FETCH_SPEED					0
	#define MON_CHECK_SPEED					1
	#define MON_MAX_SPEED					120
	#define MON_REPORT_SPEED				1	
	#define MON_REPORT_SPEED_LENGTH			5 //SXYZ<space>
	#define MON_REPORT_SPEED_TRACCAR		1
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

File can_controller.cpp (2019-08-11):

//
// Author:	Álvaro Graciá Gil
// License:	This work is licensed under a Creative Commons Attribution-NonCommercial-ShareAlike 4.0 International License 
//	 		(http://creativecommons.org/licenses/by-nc-sa/4.0/) 
//

#include "can_controller.h"
#include "cmd_serial.h"

#pragma region //******* PRIVATE ********//

#pragma region /** SEND **/  
bool CAN_CONTROLLER::sendCmdToCANController(CAN_COMMAND *cmd, uint8_t nextCmdDelay = CAN_MIN_COMMAND_INTERVAL)
{      
	#if CAN_DISABLE_INTERRUPTS_AT_TRANSFER
		uint8_t oldSREG = SREG;
		noInterrupts();
	#endif

		MCP2515::ERROR ret = CAN->sendMessage(cmd);

	#if CAN_DISABLE_INTERRUPTS_AT_TRANSFER
		SREG = oldSREG;
	#endif

	if (ret == MCP2515::ERROR_OK)
	{
		#if CAN_ENABLE_MIN_DELAY_BETWEEN_COMMANDS
			this->nextTXmillis = (millis() + nextCmdDelay);
		#endif

		if (CONFIG.get(PRINT_CAN_DATA))
			cmd->print_P(sSent);

		return true;
	}
	else
	{
		#if CAN_ENABLE_MIN_DELAY_BETWEEN_COMMANDS
			this->nextTXmillis = (millis() + CAN_TX_RETRY_TIMEOUT);
		#endif

		return false;
	}
}
#pragma endregion

#pragma region /** RECEIVE **/
bool CAN_CONTROLLER::fetchCmdFromController(CAN_COMMAND *cmd)
{        
	#if COMPILE_CAN_INTERRUPT && CAN_INTERRUPT_MODE == CAN_INTERRUPT_MODE_FLAG
		MCP2515::ERROR res;
		
		if (this->currentInterruptsReg & MCP2515::CANINTF_RX0IF) //BUFFER 0			
			res = this->CAN->readMessage(MCP2515::RXB0, cmd);		
		else if (this->currentInterruptsReg & MCP2515::CANINTF_RX1IF) //BUFFER 1		
			res = this->CAN->readMessage(MCP2515::RXB1, cmd);			
		else 
			return false;

		uint8_t oldSREG = SREG;
		noInterrupts();

			this->currentInterruptsReg = this->CAN->getInterrupts();

		SREG = oldSREG;
	#else
		MCP2515::ERROR res = this->CAN->readMessage(cmd);
		if (res != MCP2515::ERROR_OK)
			return false;
	#endif	

    #if COMPILE_CAN_BLACKLIST && CAN_BLACKLIST_LENGTH > 0
		for(unsigned char i = 0; i < this->blacklistIDsLength; i++)
			if(this->blacklistIDs[i] == cmd->can_id)
				return false;        
    #endif       
      
    return true;
}
#pragma endregion

#pragma region /** INTERRUPT **/
#if COMPILE_CAN && COMPILE_CAN_INTERRUPT      
	void CAN_CONTROLLER::handleInterrupt()
	{   
		CAN_CONTROLLER *can = &DEFAULT_CAN;
		uint8_t iReg = can->CAN->getInterrupts();

		#if CAN_HANDLE_ERRORS_ON_ONTERRUPT			
			bool iRegModified = false;
			if (iReg & MCP2515::CANINTF_ERRIF) //ERROR
			{
				uint8_t error = can->CAN->getErrorFlags();
				if (error & (MCP2515::EFLG_RX0OVR | MCP2515::EFLG_RX1OVR))
				{
					cont->modifyRegister(MCP2515::MCP_EFLG, (MCP2515::EFLG_RX0OVR | MCP2515::EFLG_RX1OVR), 0);

					iReg &= ~MCP2515::CANINTF_ERRIF; //CLEAR ERRIF
					iRegModified = true;
				}
			}

			if (iReg & MCP2515::CANINTF_MERRF)
			{
				can->CAN->clearMERR();

				iReg &= ~MCP2515::CANINTF_MERRF;
				iRegModified = true;
			}

			if (iRegModified)
				can->CAN->setRegister(MCP2515::MCP_CANINTF, iReg);
		#endif

		//FETCH RX
		#if CAN_INTERRUPT_MODE == CAN_INTERRUPT_MODE_FETCH
			CAN_COMMAND cmd;
			MCP2515::ERROR res;

			if (iReg & MCP2515::CANINTF_RX0IF)
			{
				res = can->CAN->readMessage(MCP2515::RXB0, &cmd);
				if (res == MCP2515::ERROR_OK)
					DEFAULT_CAN.rxQueue.push(&cmd);
			}

			if (iReg & MCP2515::CANINTF_RX1IF)
			{
				res = can->CAN->readMessage(MCP2515::RXB1, &cmd);
				if (res == MCP2515::ERROR_OK)
					DEFAULT_CAN.rxQueue.push(&cmd);
			}
		#elif CAN_INTERRUPT_MODE == CAN_INTERRUPT_MODE_FLAG
			#if CAN_HANDLE_ERRORS_ON_ONTERRUPT
				uint8_t rxMask = (MCP2515::CANINTF_RX0IF | MCP2515::CANINTF_RX1IF);
				DEFAULT_CAN.currentInterruptsReg = (iReg & rxMask);								
			#else
				DEFAULT_CAN.currentInterruptsReg = iReg;
			#endif
		#endif	
	} 
#endif
#pragma endregion

#pragma region /** RX & TX QUEUE **/
bool CAN_CONTROLLER::readyToSendCmd()
{
	#if CAN_ENABLE_MIN_DELAY_BETWEEN_COMMANDS
		return (this->nextTXmillis <= millis());
	#else
		return true;
	#endif
}

bool CAN_CONTROLLER::cmdAvailableInRXQueue()
{
	return !rxQueue.isEmpty();
}

bool CAN_CONTROLLER::cmdAvailableInController()
{	
	#if COMPILE_CAN_PIN_CMD_AVAILABLE
		#if COMPILE_CAN_INTERRUPT && CAN_INTERRUPT_MODE == CAN_INTERRUPT_MODE_FLAG
			return (this->currentInterruptsReg);
		#else
			return (digitalRead(this->intPin) == LOW);
		#endif
	#else		
		return this->CAN->checkReceive();
	#endif
};

uint8_t CAN_CONTROLLER::fillRXQueueFromCANController(uint8_t maxCmds = CAN_RX_QUEUE_LENGTH)
{
	uint8_t i = 0;
	for (; cmdAvailableInController() && !this->rxQueue.isFull() && i < maxCmds; i++)
	{
		CAN_COMMAND cmd;
		if (this->fetchCmdFromController(&cmd))
			this->rxQueue.push(&cmd);
		else
			break;
	}

	return i;
}

#if CAN_ENABLE_TX_QUEUE && CAN_TX_QUEUE_LENGTH > 0
	bool CAN_CONTROLLER::pullTXCmd(CAN_COMMAND *cmd)
	{
		return txQueue.pull(cmd);
	}

	bool CAN_CONTROLLER::pushTXCmd(CAN_COMMAND *cmd)
	{
		return txQueue.push(cmd);
	}
#endif

#pragma endregion

#pragma region /* PERIODICAL CMDS */
#if COMPILE_CAN_PERIODICAL && CAN_PERIODICAL_CMDS_LENGTH > 0
void CAN_CONTROLLER::checkPeriodicalCmds()
{
	unsigned long now = millis();
	for (uint8_t i = 0; i < this->periodicalCmdsLength; i++)
	{
		CAN_COMMAND_PERIODICAL *per = this->periodicalCmds[i];
		if (now >= per->nextMillis)
		{
			if (sendCmd(per->cmd))
				per->nextMillis += per->interval;
			else
				break;
		}
	}
}
#endif
#pragma endregion

#pragma endregion

#pragma region //******* PUBLIC ********//
CAN_CONTROLLER::CAN_CONTROLLER(const uint8_t csPin, const uint8_t intPin, void (*h)(CAN_CONTROLLER*, CAN_COMMAND*)) : intPin(intPin), receiveHandler(h)
{
	this->CAN = new MCP2515(csPin);

	#if CAN_ENABLE_MIN_DELAY_BETWEEN_COMMANDS
		this->nextTXmillis = 0;
	#endif  
    #if COMPILE_CAN_WHITELIST
		this->whitelistLength = 0;
    #endif
    #if COMPILE_CAN_BLACKLIST && CAN_BLACKLIST_LENGTH > 0
		this->blacklistIDsLength = 0;   
    #endif        
    #if COMPILE_CAN_PERIODICAL && CAN_PERIODICAL_CMDS_LENGTH > 0
		this->periodicalCmdsLength = 0;     
    #endif
}

void CAN_CONTROLLER::setupPins()
{
	#if COMPILE_CAN_PIN_CMD_AVAILABLE
		pinMode(this->intPin, INPUT_PULLUP);
	#endif
}

bool CAN_CONTROLLER::begin(const CAN_SPEED bitrate, const CAN_CLOCK clockSet)
{     	
	SPI.begin();
	
	this->CAN->reset();
	if (this->CAN->setBitrate(bitrate, clockSet) != MCP2515::ERROR_OK)
		return false;

	#if COMPILE_CAN_WHITELIST
		if (!this->setupWhitelist())
			return false;
	#endif

	#if CAN_MODE_LOOPBACK	
		if (this->CAN->setLoopbackMode() != MCP2515::ERROR_OK)
	#else
		if (this->CAN->setNormalMode() != MCP2515::ERROR_OK)
	#endif
		return false;

	#if COMPILE_CAN_PIN_CMD_AVAILABLE && COMPILE_CAN_INTERRUPT
		this->enableInterrupts();
	#endif   
    
    return true;    
}
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

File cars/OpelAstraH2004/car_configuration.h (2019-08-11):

//
// Author:	Álvaro Graciá Gil
// License:	This work is licensed under a Creative Commons Attribution-NonCommercial-ShareAlike 4.0 International License 
//	 		(http://creativecommons.org/licenses/by-nc-sa/4.0/) 
//

//Timer0 --> Millis, nanos
//Timer1 --> POW On -> DIS || POW Off -> Alarm LED
//Timer2 --> GPS notification task

//INJECTION	
#define INJECT_PERIODICAL_CAR_COMMANDS	1
#define INJECT_DIS_BC_RESPONSE			1
#define INJECT_DOOR_OPEN				1

//BUTTON EVENTS
#define ENABLE_BUTTON_EVENT_HANDLING	1
#define COMPILE_SETTINGS_MODE			1
#define ENABLE_DIS_BUTTON_FLAGS			1

#define NONE_MASK						0
#define LEFT_WHEEL_BUTTON_MASK			(1 << 5)
#define RIGHT_TOP_BUTTON_MASK			(1 << 4)
#define RIGHT_BOTTOM_BUTTON_MASK		(1 << 3)
#define LEFT_TOP_BUTTON_MASK			(1 << 2) //DIS -> REG
#define LEFT_BOTTOM_BUTTON_MASK			(1 << 1) //DIS -> RDS
#define SETTINGS_MODE_MASK				(1 << 0) //DIS -> AS

//MSCAN 
#define CAN_BAUDRATE					CAN_95KBPS
#define CAN_BLACKLIST_LENGTH            0  //items
#define CAN_PERIODICAL_CMDS_LENGTH      1  //items
#define CAN_FRIEND_FUNCTION				bool astraHDISRequestText(CAN_CONTROLLER *can)

//ALARM LED
#define COMPILE_ALARM_LED				0
#define ALARM_LED_TICK_INTERVAL         200 //ms
#define ALARM_LED_ON_TICKS              1  
#define ALARM_LED_OFF_TICKS             20 
#define ALARM_LED_USE_TIMER_ONE			0
#define ALARM_LED_PIN					GPIO1_PIN  

//STATUS MONITOR
#define MON_ON_ALARM_STATUS_CHANGED_HANDLER		astraHOnAlarmStatusChanged

#define MON_VOLTAGE_MEASURING_BLOCK_ID			0x00 //UNKNOWN
#define MON_VOLTAGE_DIS_REPORT					1

#define MON_TEMP_MEASURING_BLOCK_ID				0x0B
#define MON_TEMP_DIS_REPORT						1

#define MON_SPEED_MEASURING_BLOCK_ID			0x00 //UNKNOWN
#define MON_SPEED_DIS_REPORT					1

//BC
#define COMPILE_BC_ECHO					0	//Required to avoid MS-CAN OPCOM errors

//DIS
const char PROGMEM DIS_MESSAGE[]		= { "Opel Astra H" };
#define COMPILE_DIS						0
#define DIS_MESSAGE_USES_PROGMEM		1
#define DIS_TICK_INTERVAL               200 //ms
#define DIS_REFRESH_TICKS               15  //MAX 17
#define DIS_TEXT_TIMEOUT_TICKS          50	//10s
#define DIS_TEXT_START_END_TICKS        5	//1s
#define DIS_TEXT_STEP_TICKS             1	//200ms
#define DIS_MAX_CHARACTERS              14 
#define DIS_MAX_TEXT_LENGTH             32  
#define DIS_SEND_COMMANDS_IMMEDIATELY	0
#define DIS_USE_TIMER_ONE               0 //IF ENABLED, CAN TX QUEUE MUST DISABLE INTERRUPTIONS
#define DIS_SIMULATE_BC_RESPONSE        0

//TEST MODE
#define COMPILE_TEST_MODE				0
#define TEST_MODE_TX_INTERVAL			40 //ms
#define TEST_MODE_INITIAL_DELAY			500 //ms

//REMOTE DOOR
#define REMOTE_DOOR_MODE_NONE			0
#define REMOTE_DOOR_MODE_RC				1
#define REMOTE_DOOR_MODE_SWITCH			2

#ifdef GPIO1_PIN
	#define COMPILE_REMOTE_DOOR								1
	#define REMOTE_DOOR_MODE								REMOTE_DOOR_MODE_SWITCH
#else
	#define COMPILE_REMOTE_DOOR								0
	#define REMOTE_DOOR_MODE								REMOTE_DOOR_MODE_NONE
#endif

const char PROGMEM REMOTE_DOOR_0_DIS_MESSAGE[] =		{ "Entrada garaje" };
#ifdef GPIO2_PIN
	const char PROGMEM REMOTE_DOOR_1_DIS_MESSAGE[] =		{ "Salida garaje" };
#endif
#define REMOTE_DOOR_SIGNAL_SEND_INTERVAL				1000 //ms
#define REMOTE_DOOR_MODE_RC_PULSE_LENGTH				321
#define REMOTE_DOOR_MODE_RC_REPEAT_TRANSMIT				10
#define REMOTE_DOOR_MODE_RC_PIN							GPIO1_PIN

#if ENABLE_INJECTION
	#undef COMPILE_DIS
	#undef COMPILE_TEST_MODE
	#undef COMPILE_REMOTE_DOOR
	#undef COMPILE_ALARM_LED
	#undef CAN_PERIODICAL_CMDS_LENGTH

	#if INJECT_PERIODICAL_CAR_COMMANDS
		#define PER_CAR_COMMANDS_LENGTH 5
	#else
		#define PER_CAR_COMMANDS_LENGTH 0
	#endif

	#if INJECT_DOOR_OPEN
		#define PER_DOOR_OPEN_LENGTH 4
	#else
		#define PER_DOOR_OPEN_LENGTH 0
	#endif

	#define COMPILE_DIS					0
	#define COMPILE_TEST_MODE			0
	#define COMPILE_REMOTE_DOOR			0
	#define COMPILE_ALARM_LED			0
	#define CAN_PERIODICAL_CMDS_LENGTH	(PER_CAR_COMMANDS_LENGTH + PER_DOOR_OPEN_LENGTH)
#endif

//CONFIGURATION
#define PRINT_DISPLAY_INFO				(1 << 8)
#define ENABLE_POWER_NOTIFICATION		(1 << 9)
#define ENABLE_RADIO_SIMULATION			(1 << 10)
#define ENABLE_TEST_MODE				(1 << 11)
#define ENABLE_DISPLAY					(1 << 12)
#define ENABLE_RANDOM_TEXTS				(1 << 13)
#define ENABLE_ALARM_LED				(1 << 14)
#define ENABLE_CAR_STATUS_MONITOR		(1 << 15)

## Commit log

2018-12-09 Repository rebuilt with the latest project version
    [configuration.h, configuration_eeprom.h, configuration_secret_template.h]
2018-12-10 Added the latest board schema and gerber files.
2018-12-10 Included several images and STL files of the case and the cover.
    [Case V4.3.stl, Cover V4.3.stl]
2019-02-18 Added Creative Commons license.
    [configuration.h, configuration_eeprom.h, configuration_secret_template.h]
2019-08-11 Changes in cmdSerial.
    Now allows multiple command serials at the same time.
    Note: cmd handlers answers only to origin serial interface.
    [configuration.h]
2019-11-21 Upload code
    [configuration.h, configuration_eeprom.h, configuration_secret_template.h]
